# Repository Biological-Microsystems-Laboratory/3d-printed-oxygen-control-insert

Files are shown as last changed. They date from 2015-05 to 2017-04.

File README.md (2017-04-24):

# 3d-printed-oxygen-control-insert
### A 3D-printable microfluidic device for controlling dissolved gas environment in a 24-well culture plate

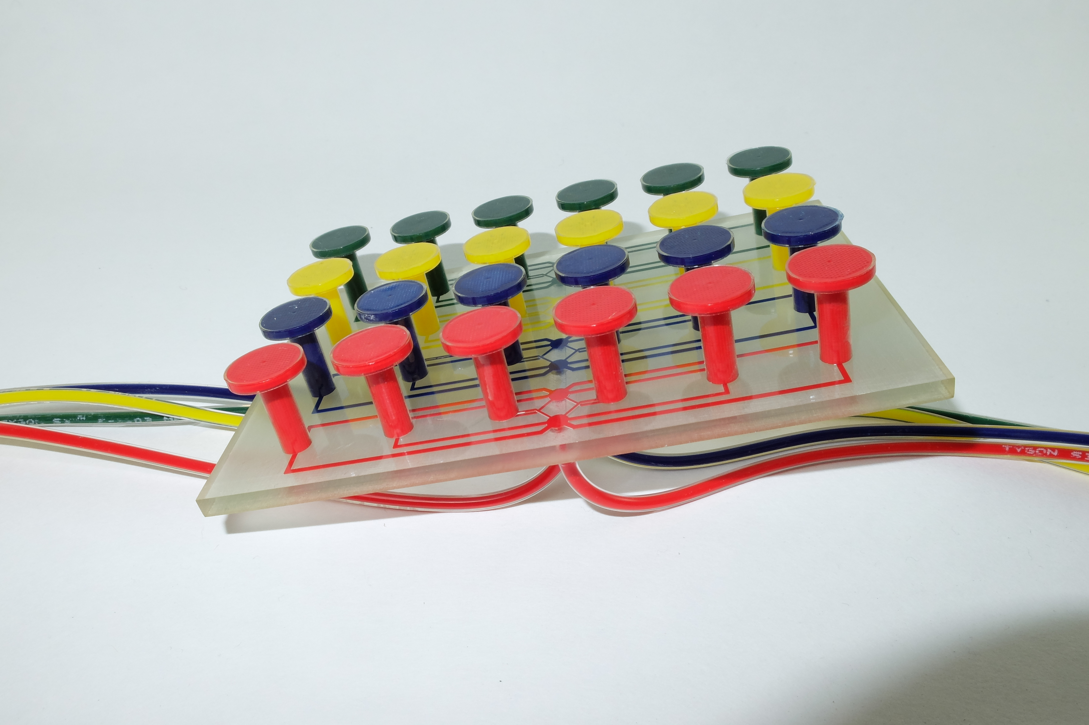
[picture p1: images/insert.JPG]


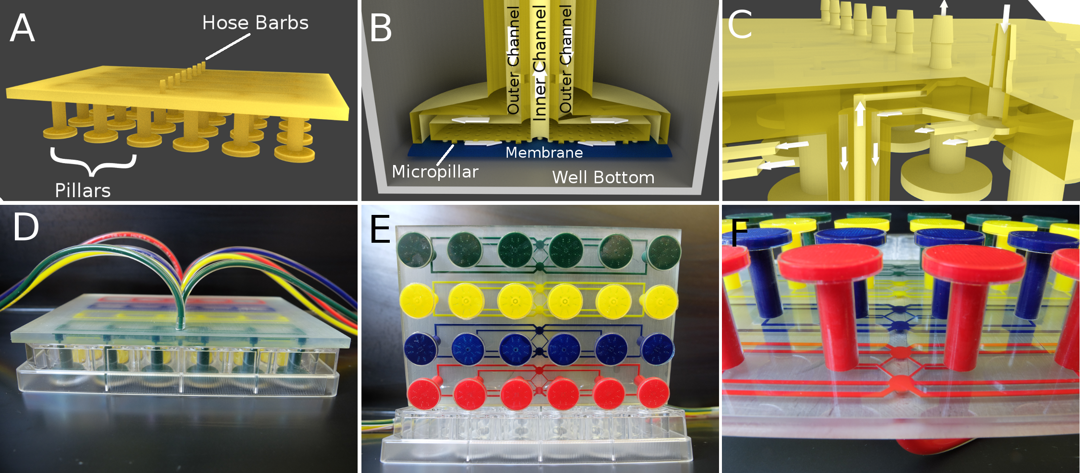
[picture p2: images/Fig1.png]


#### The device is printed complete with embedded channels and hose barbs. A 150 micrometer PDMS membrane is adhered to the pillar bottoms to complete the fluidic network and facilitate gas diffusion. Dissolved gas can be controlled in four 6-well units of a 24-well plate. 

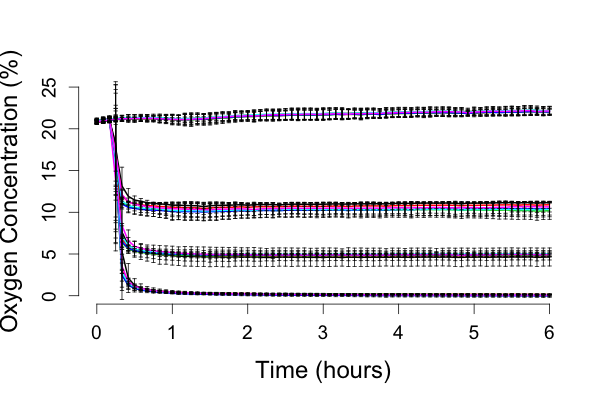
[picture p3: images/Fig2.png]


#### Dissolved oxygen at the cell culture surface can be modulated to near zero or up to 4 discrete levels.

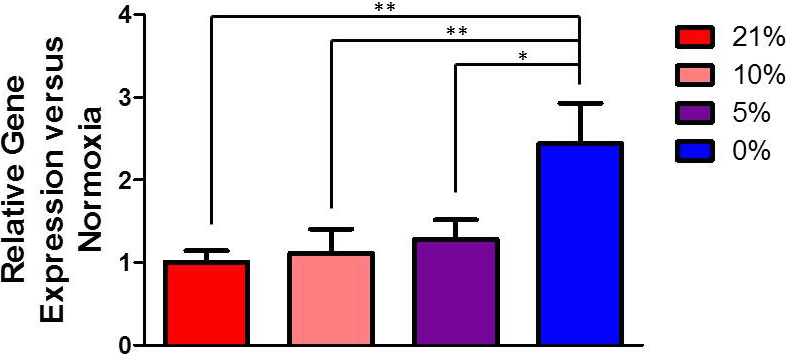
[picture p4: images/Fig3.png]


#### Oxygen levels influence VEGFA expression in A594 cells.

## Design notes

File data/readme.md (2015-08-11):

Data Plan
---
Demonstrate each row of 6 wells applying the condition of 0 5 10 or 21.

Calibrate with conditions of 0%, 1%, 7.5%, 15%, and 21%.

Calibration Procedure
------

1. Bring all wells to 0% with sodium sulfite (2 g/L) and device running with 0%. ~2hrs take final points as zero
2. With fresh water take wells to zero with 0% tank. ~2hrs
3. Switch to 1% tank. Take 1% calibration point. ~ 20 min
4. Switch to 7.5% tank. Take cal point. ~ 20 min
5. Switch to 15% tank. Take cal point. ~ 20 min
6. Exchange plate with fresh room equilibrated water. Switch to 21% tank Take cal point.

Charaterization Procedure
----
1. Change set-up to experimental tanks (0%, 5%, 10% and 21%)
2. Start all rows pulling room air.
3. Take acquisition every 5 min for 6 hrs.
4. Start pulling the characterization condition for each well after third timepoint.

Data organization
---

Intensities for each trial (N) will be stored here rather then raw images.

Intensities calibration matrix 24:5 (C:R) and characterization matrix 24:73

Detail Set-up
------------
4 CGA 500 two-stage regulators
2 Omega foating ball adjustable flow meters (FL-5311G rotameters)
#### Air Tanks
0%   O2, 5% CO2, bal. N2 tank
1%   O2, 5% CO2, bal. N2 tank; BI NICDOXC5-K
5%   O2, 5% CO2, bal. N2 tank; BI NICDOXC1-K
7.5% O2, 5% CO2, bal. N2 tank; BI NICD5017-K
10%  O2, 5% CO2, bal. N2 tank; BI NICDOX C21-K
15%  O2, 5% CO2, bal. N2 tank; BG NICDOXC43-K
21%  O2, 5% CO2, bal. N2 tank; BI NICDOXC4-K
Air tank, atomospheric mix

Sodium Sulfite (SS)

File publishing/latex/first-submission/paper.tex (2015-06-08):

% Template for PLoS
% Version 3.1 February 2015
%
% To compile to pdf, run:
% latex plos.template
% bibtex plos.template
% latex plos.template
% latex plos.template
% dvipdf plos.template
%
% % % % % % % % % % % % % % % % % % % % % %
%
% -- IMPORTANT NOTE
%
% This template contains comments intended 
% to minimize problems and delays during our production 
% process. Please follow the template instructions
% whenever possible.
%
% % % % % % % % % % % % % % % % % % % % % % % 
%
% Once your paper is accepted for publication, 
% PLEASE REMOVE ALL TRACKED CHANGES in this file and leave only
% the final text of your manuscript.
%
% There are no restrictions on package use within the LaTeX files except that 
% no packages listed in the template may be deleted.
%
% Please do not include colors or graphics in the text.
%
% Please do not create a heading level below \subsection. For 3rd level headings, use \paragraph{}.
%
% % % % % % % % % % % % % % % % % % % % % % %
%
% -- FIGURES AND TABLES
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
% - Figures generated using LaTeX should be extracted and removed from the PDF before submission. 
% - Figures containing multiple panels/subfigures must be combined into one image file before submission.
% For figure citations, please use "Fig." instead of "Figure".
% See http://www.plosone.org/static/figureGuidelines for PLOS figure guidelines.
%
% Tables should be cell-based and may not contain:
% - tabs/spacing/line breaks within cells to alter layout or alignment
% - vertically-merged cells (no tabular environments within tabular environments, do not use \multirow)
% - colors, shading, or graphic objects
% See http://www.plosone.org/static/figureGuidelines#tables for table guidelines.
%
% For tables that exceed the width of the text column, use the adjustwidth environment as illustrated in the example table in text below.
%
% % % % % % % % % % % % % % % % % % % % % % % %
%
% -- EQUATIONS, MATH SYMBOLS, SUBSCRIPTS, AND SUPERSCRIPTS
%
% IMPORTANT
% Below are a few tips to help format your equations and other special characters according to our specifications. For more tips to help reduce the possibility of formatting errors during conversion, please see our LaTeX guidelines at http://www.plosone.org/static/latexGuidelines
%
% Please be sure to include all portions of an equation in the math environment.
%
% Do not include text that is not math in the math environment. For example, CO2 will be CO\textsubscript{2}.
%
% Please add line breaks to long display equations when possible in order to fit size of the column. 
%
% For inline equations, please do not include punctuation (commas, etc) within the math environment unless this is part of the equation.
%
% % % % % % % % % % % % % % % % % % % % % % % % 
%
% Please contact latex@plos.org with any questions.
%
% % % % % % % % % % % % % % % % % % % % % % % %

\documentclass[10pt,letterpaper]{article}
\usepackage[top=0.85in,left=2.75in,footskip=0.75in]{geometry}

% Use adjustwidth environment to exceed column width (see example table in text)
\usepackage{changepage}

% Use Unicode characters when possible
\usepackage[utf8]{inputenc}

% textcomp package and marvosym package for additional characters
\usepackage{textcomp,marvosym}

% fixltx2e package for \textsubscript
\usepackage{fixltx2e}

% amsmath and amssymb packages, useful for mathematical formulas and symbols
\usepackage{amsmath,amssymb}
\usepackage[version=3]{mhchem}  % added by author

% cite package, to clean up citations in the main text. Do not remove.
\usepackage{cite}

% Use nameref to cite supporting information files (see Supporting Information section for more info)
\usepackage{nameref,hyperref}

% line numbers
\usepackage[right]{lineno}

% ligatures disabled
\usepackage{microtype}
\DisableLigatures[f]{encoding = *, family = * }

% rotating package for sideways tables
\usepackage{rotating}

% Remove comment for double spacing
%\usepackage{setspace} 
%\doublespacing

% Text layout
\raggedright
\setlength{\parindent}{0.5cm}
\textwidth 5.25in 
\textheight 8.75in

% Bold the 'Figure #' in the caption and separate it from the title/caption with a period
% Captions will be left justified
\usepackage[aboveskip=1pt,labelfont=bf,labelsep=period,justification=raggedright,singlelinecheck=off]{caption}

% Use the PLoS provided BiBTeX style
\bibliographystyle{plos2015}

% Remove brackets from numbering in List of References
\makeatletter
\renewcommand{\@biblabel}[1]{\quad#1.}
\makeatother

% Leave date blank
\date{}

% Header and Footer with logo
\usepackage{lastpage,fancyhdr,graphicx}
\usepackage{epstopdf}
\pagestyle{myheadings}
\pagestyle{fancy}
\fancyhf{}
\lhead{}
\rfoot{\thepage/\pageref{LastPage}}
\renewcommand{\footrule}{\hrule height 2pt \vspace{2mm}}
\fancyheadoffset[L]{2.25in}
\fancyfootoffset[L]{2.25in}
\lfoot{\sf PLOS}

%% Include all macros below

\newcommand{\lorem}{{\bf LOREM}}
\newcommand{\ipsum}{{\bf IPSUM}}

%% END MACROS SECTION

\begin{document}
\vspace*{0.35in}

% Title must be 250 characters or less.
% Please capitalize all terms in the title except conjunctions, prepositions, and articles.
\begin{flushleft}
{\Large
\textbf\newline{3D-Printed 24-Well Plate Oxygen Control Device - Submission to PLOS ONE}
}
\newline
% Insert author names, affiliations and corresponding author email (do not include titles, positions, or degrees).
\\
Martin D. Brennan\textsuperscript{1},
Megan L. Rexius-Hall\textsuperscript{1},
David T. Eddington\textsuperscript{1,*},
\\
\bigskip
\bf{1} Dept of Bioengineering, University of Illinois at Chicago, Chicago, Illinois, USA
\\
\bigskip

% Use the asterisk to denote corresponding authorship and provide email address in note below.
* dte@uic.edu

\end{flushleft}
% Please keep the abstract below 300 words
\section*{Abstract}
Recently 3D printing has emerged as a method for directly printing complete microfluidic devices, although printing materials have been limited to oxygen-impermeable materials.
We demonstrate the addition of gas permeable PDMS (Polydimethylsiloxane) membranes to 3D-printed microfluidic devices as a means to enable oxygen control cell culture studies.
The incorporation of a 3D-printed device and gas-permeable membranes was demonstrated on a 24-well oxygen control device for standard multiwell plates.
The direct printing allows integrated distribution channels and device geometries not possible with traditional planar lithography.
With this device, four different oxygen conditions were able to be controlled, and six wells were maintained under each oxygen condition. 
We demonstrate enhanced transcription of the gene VEGFA (vascular endothelial growth factor A) with decreasing oxygen levels in human lung adenocarcinoma cells.
This is the first 3D-printed device that can be functionalized to control oxygen in cell culture.

\linenumbers

\section*{Introduction}
Here we report on the development of 3D-printed microfluidic devices for the control of oxygen in cell culture microenvironments.
We demonstrate a device that nests into a 24-well culture plate to control gas in each row of the plate independently of the incubator's condition.
This expands on our previous work of a device fabricated using PDMS molds and planar lithography for 6-well plates\cite{Oppegard2009,Oppegard2010}.
The ability to independently control oxygen across each row of the plate enables more efficient experiments as a separate incubator or hypoxic chamber is not needed for each condition.

3D printing of microfluidic devices enables rapid, one-step fabrication of complex designs infeasible to make with planar lithography and replica molding techniques\cite{Waldbaur2011,Chen2014a}.
In addition, planar lithography is time consuming, requires specialized equipment and facilities, and has a high failure rate.
It is not unusual for microfluidic labs to make ten microfluidic devices to guarantee one will work properly.
On the other hand, 3D CAD printing allows for unambiguous specifications and nearly eliminates time and effort spent on fabrication which may be outsourced to a 3D printing company for around \$200/device \cite{Au2014}.
3D printing also allows integration of complex geometries not possible with planar lithography, such as hose barbs and luer fittings.
Dissemination and distributed production is also vastly simplified due to easy sharing of the design as a CAD file.
Due to these inherent advantages 3D printing has emerged as a method for directly printing complete microfluidic devices \cite{Au2014,Comina2014, Chen2014,Shallan2014,Bhargava2014}. 
Many prototypical microfluidic device features have been recreated with 3D printing as a proof of concept for this new fabrication technique \cite{ Au2014, Shallan2014} including modular re-configurable units\cite{Yuen2008,Bhargava2014,Lee2014}.
3D printed devices have been used for neuroengineering applications\cite{Tek2008}, inexpensive and high-throughput reactionware,\cite{Kitson2012,Symes2012,Kitson2013,Kitson2014}, culturing and imaging arrays of seedlings\cite{Busch2012}, measuring dopamine and ATP levels in biological samples with an integrated electrode\cite{Erkal2014}, or plate reader\cite{Chen2014}, and a bacteria separation flow assay\cite{Lee2014a,Lee2015}. 
Other 3D-printed fluidic devices include pneumatic valves\cite{Au2015} a custom NMR cell\cite{Causier2015}, a rapid reconstitution package for lyophilized drugs\cite{Chi2014} and flow plates for a water electrolysis system\cite{Chisholm2014}.

Printing is currently limited in choice of substrate compatible with the 3D printing process.
Substrate options include many proprietary formulations which have been successfully used in a variety of applications.
New techniques for using 3D-printed molds to produce devices\cite{Mcdonald2002,Gregory2013,King2014,Comina2014a,Kamei2015} are also being developed, including fugitive ink methods\cite{Therriault2003,Miller2012,Bhargava2015}.
To date, there are no widely available methods or materials to facilitate direct printing of gas-permeable materials, although this area is actively being explored\cite{Femmer2014a}.
Microfluidic cell culture devices are most commonly cast in PDMS as it is a convenient material for cell studies due to its biocompatibility, optical properties, and gas permeability, facilitating oxygen control of cell environments\cite{Sia2003,Brennan2014}.

Oxygen control in cells studies is often overlooked by researchers, but important for mimicking conditions experienced by cells in vivo.
Typically cell culture studies are performed at 21\% oxygen, atmospheric oxygen conditions, although levels that cells experience in vivo are less than 21\% \cite{Brennan2014}.
For example, tumors are generally hypoxic as cancer cells rapidly outgrow their vasculature creating a poorly perfused, hypoxic inner region\cite{Kumar2014}.
Studying cancer cells under controlled hypoxic conditions is important in understanding the pathophysiology because research has shown hypoxia may enhance aggressive phenotypes, tumor progression, metastasis, and resistance to therapy\cite{Vaupel2004,Vaupel2007,Gilkes2014}.
Hypoxia is known to alter the transcription of many genes which are under the activity of the HIF (hypoxia inducible factor) family of transcriptional factors\cite{Ke2006,Semenza1999,Semenza2002}.
To better study the role of oxygen levels in cancer gene expression, a gas controlled culture system is required.

Previously, we developed multiwell inserts for 6-well plates that controlled oxygen in a standard off-the shelf well plate \cite{Oppegard2009, Oppegard2010}.
These devices were completely cast from PDMS and fabricated in a multiple bonding procedure.
In addition, tubing was used to connect each pillar which became quite cumbersome when moving to a newer 24-well version.
Utilizing 3D printing for the fabrication allowed further features to be incorporated such as integrated distribution channels to eliminate the connection tubings between wells and hose barbs for better tubing connections, while eliminating fabrication time and failure rate.
Although available 3D printable materials are gas-impermeable, the addition of a PDMS membrane following printing of the passive microfluidic network is a simple addition allowing gas transfer. 
In this case, having a gas-impermeable material for the bulk is advantageous as it reduces unwanted gas transfer from the bulk material prior to the gas exchange interface.
The previous PDMS devices were Parylene coated along the convection channels to eliminate exchange of gas from the PDMS bulk, which again added to their complexity and is no longer needed.
Convection and distribution of the gas is done in the impermeable material, eliminating dilution of the gas before reaching the diffusion layer. 

% You may title this section "Methods" or "Models". 
% "Models" is not a valid title for PLoS ONE authors. However, PLoS ONE
% authors may use "Analysis" 
\section*{Materials and Methods}
\subsection*{Design of insert}

The device was designed to integrate with a multiwell format, specifically an off-the-shelf 24-well plate. 
The 24-well plate insert was designed to control gas in 4 rows of 6 wells each. 
Each of the 4 rows can be controlled independently from an input and also incorporates an integrated distribution network and hose barbs to simplify device operation.
The pillars extend into each well leaving a $\sim$500 $\mu$m gap for media between the diffusion membrane and the culture surface at the bottom of the well.
Diffusion occurs rapidly across this gap allowing control of the dissolved gas environment around the cells. 
A distribution network stems from the central input that equalizes the flow along each path length by varying the channel width to the proximal, intermediate, and distal wells (Fig.~\ref{fig1}).
The device also features a pipe within a pipe design so that gas flow enters and leaves the diffusion area in a uniform, and symmetrical flow pattern, which would not be possible with standard lithography and demonstrates the capabilities of 3D printing (Fig.~\ref{fig1}).

\begin{figure}[h]
\caption{
{\bf Design of 24-well Insert Device.}
(A) Rendering of whole 3D printed part.
An inlet and outlet barb allows perfusion of gas to control 6 wells.
(B) At the bottom of each pillar gas entering from the outer channel flows along the PDMS membrane (blue), which is supported by micropillars, and exhausts via the inner pipe.
Diffusion occurs rapidly through the PDMS membrane to the cell culture spaced 500 $\mu$m away at the bottom of the well.
(C) Cross-section demonstrating how the microfluidic distribution network and double pipes are connected. 
The two adjacent mirrored distribution networks are spaced 1 mm apart along the z-axis allowing them to overlap and enter the separate vertical pipes.
The arrows indicate the flow direction.
The incoming gas enters the outer pipe on its way to the bottom of the well and returns through the inner pipe.
(D) Photo of the device with dyed channels in a 24-well plate.
(E) Photo of the device from the bottom with four independent channel networks.
(F) Photo of the printed distribution networks.
}
\label{fig1}
\end{figure}

\subsection*{Fabrication of the insert}

CAD models were designed in Autodesk and Blender and printed via stereolithography in Watershed XC by Fineline Prototyping.
The 3D part contained the microfluidic delivery channels, and was completed by adhering a gas-permeable membrane of PDMS to enable diffusion of gas to the culture area. 
The PDMS membranes were fabricated by spin coating 10:1 PDMS (Sylgard 184) on a silicon wafer at 900 RPM to a thickness of $\sim$100 $\mu$m and curing at $70\,^{\circ}$C for 30 minutes.
The PDMS membrane was cut to size and attached to the 3D-printed network with an additional, thin layer of PDMS that was applied as an adhesive to the membrane, secured in position on the end of each pillar, and allowed to cure in place.

\subsection*{Oxygen characterization}

Oxygen was measured with PtOEPK (Pt(II) Octaethylporphine ketone) planar sensors that were fixed to the bottom of a 24-well plate.
Sensors were prepared as discussed previously \cite{Sinkala2010,Rexius-Hall2014}. 
Briefly, polystyrene was dissolved in toluene to form a solution to which PtOEPK (Frontier Scientific) was mixed in before spin coating to a thin layer and allowing the toluene to evaporate.
The intensity of the sensor was measured with via fluorescence microscopy and correlated to the concentration of oxygen with Stern-Volmer analysis.

Gas was pulled through the device with negative pressure as a precaution to avoid bulging or detaching membranes, as well as bubble formation in the culture media.
The outlet ports were connected to a water aspirator which pulled gas through the device from the inlet ports via a flow meter (FL-5311G; Omega) set at 50 ccm.
The inlet tubing was placed in an open cone that was flooded with gas from a tank with a flow rate of 30 ccm which exceed the vacuum flow rate (12.5 ccm per 6-well network) so that the gas of interest was pulled into the inlet rather than room air due to the open connection.
In this way, the pressure, and therefore flow rate, was equal across the 4 networks without having to balance flow from 4 pressurized sources, yet different gases of interest can be perfused via vacuum.

Initially the inlets are fed with a 5\% \ce{CO2}, balanced air tank until the intensity stabilized.
The inlets were then switched to the control gas of either 0, 5, 10, or 21\% \ce{O2}, each with 5\% \ce{CO2} and balanced with \ce{N2}.
Intensity measurements were then taken every five minutes for six hours.
All gas tanks used in the oxygen characterization were 5\% \ce{CO2}  in addition to the desired gas mix in anticipation of cell culture experiments (where \ce{CO2} is necessary to buffer the culture media) as \ce{CO2} can alter the fluorescence of the PtOEPK.
The this entire procedure was repeated three independent times. 

\subsection*{Cell culture}

Human lung adenocarcinoma (A549) cells were seeded at 30,000 cells per well in a 24-well plate.
Cells were cultured in DMEM supplemented with 10\% FBS.
After reaching $\sim$70\% confluency, the 24-well insert was placed in the plate and the gases were perfused through the device in the same scheme as in the oxygen characterization.
Each row of six wells experienced either 0\%, 5\%, 10\% or 21\% \ce{O2}, with 5\% \ce{CO2} and balanced nitrogen.
The assembly was placed in an incubator at $37\,^{\circ}$C for six hours. 

\subsection*{Quantitative PCR}

Following six hours of oxygen modulation, the 24-well oxygen control insert was removed and culture media was aspirated.
Cells in each well were washed twice with PBS, and 300 $\mu$L of a lysis solution consisting of 10 $\mu$L of $\beta$-mercaptoethanol (Sigma Aldrich) per 1 mL of lysis buffer (PureLink RNA Mini Kit; Invitrogen) was added to each well.
The lysate from each well was collected as a sample.
RNA was extracted according to the PureLink RNA Mini Kit manufacturer’s instructions.

Synthesis of cDNA was performed using the High-Capacity cDNA Reverse Transcription Kit (Applied Biosystems), and quantitative PCR was carried out on ABI PRISM 700O (Applied Biosystems) in 25 $\mu$L reactions using Taqman Gene Expression Assays.
Beta-2-microglobulin (B2M) served as the endogenous control for calculations of relative gene expression.
Six technical replicates from the 6-well control unit were processed for each of four oxygen conditions (0\%, 5\%, 10\% and 21\% \ce{O2}) in three independent experiments.

\subsection*{Statistical analysis}

Cell culture experiments were repeated three independent times. Data are expressed as the mean $\pm$ SD. One-way ANOVA with Tukey’s multiple comparison post-test performed by Prism 5 (Graphpad) determined significance.

% For figure citations, please use "Fig." instead of "Figure".
%Nulla mi mi, Fig.~\ref{fig1} venenatis sed ipsum varius, volutpat euismod diam. Proin rutrum vel massa non gravida. Quisque tempor sem et dignissim rutrum. Lorem ipsum dolor sit amet, consectetur adipiscing elit. Morbi at justo vitae nulla elementum commodo eu id massa. In vitae diam ac augue semper tincidunt eu ut eros. Fusce fringilla erat porttitor lectus cursus, \nameref{S1_Video} vel sagittis arcu lobortis. Aliquam in enim semper, aliquam massa id, cursus neque. Praesent faucibus semper libero.

%\begin{enumerate}
%\item{react}
%\item{diffuse free particles}
%\item{increment time by dt and go to 1}
%\end{enumerate}

% Results and Discussion can be combined.
\section*{Results}
\subsection*{Oxygen control}
Oxygen control in the 24-well insert device was quantified with a platinum-based (PtOEPK) planar oxygen sensor placed at the bottom of the well, as shown in Fig.~\ref{fig2}.
The device reaches steady state in 30 minutes and can then hold the oxygen level near 0\% \ce{O2} indefinitely, while 95\% \ce{N2}, 5\% \ce{CO2} is pumped through the device. 
A different gas condition can be used in each separate iteration of the 6-well unit allowing 6 technical replicates of up to 4 different gas conditions in one 24-well plate (Fig.~\ref{fig2}). There was little variation in the oxygen levels measured in each of the 6 wells controlled by a single inlet, demonstrating the distribution network worked effectively.

\begin{figure}[h]
\caption{
{\bf Oxygen Characterization.} 
(A) Time course data of oxygen being evacuated from the culture area as 0\% oxygen gas is perfused through the device.
Error bars are the standard deviation N=3.
(B) Four oxygen conditions are demonstrated in a 24-well plate.
Each 6-well row of the plate can be controlled independently.  
Mean N=3 error bars not included.
}
\label{fig2}
\end{figure}

\subsection*{Bioverifcation}

Oxygen levels of 21\%, 10\%, 5\%, and 0\% were applied to each set of 6 wells in which A549 cells were cultured.
Measurement of relative gene expression confirmed biological responsiveness of cells under the device’s control.
The device’s ability to control the gas environment was demonstrated with hypoxia-induced upregulation of VEGFA mRNA in the A549 cells (Fig.~\ref{fig3}).  Quantitative PCR showed a significant increase in the relative gene expression of VEGFA in wells exposed to 0\% \ce{O2} for 6 hours as compared to 21\% \ce{O2}. Hypoxia-induced alterations in gene expression usually indicate a HIF-transduced hypoxic signal in cells.
When a HIF transcription factor undergoes nuclear translocation, it can initiate transcription of genes by binding to the hypoxia response element (HRE)\cite{Lee2004} on its target genes.
VEGFA has previously been shown to have a functional HRE, and upregulation has been observed in A549 cells under hypoxic conditions\cite{RohrerBley2011}.

\begin{figure}[h]
\caption{
{\bf PCR Data.}  VEGFA expression in A549 cells after exposure to different oxygen conditions set-up by the insert device. Data are expressed as mean $\pm$ SD, N=3.
}
\label{fig3}
\end{figure}

\subsection*{Discussion}
This new iteration of the multi-well insert for oxygen control maintains the convenient features of the previous design while improving distribution and interfacing with tubing due to the 3D-printed element.
Oxygen control is performed in an off-the-shelf culture plate allowing standard protocols to be used for analysis assays or imaging where additional protocols are often required when cells are seeded within microfluidic chips.
The VEGFA gene expression in A549 cells confirms a biological response using the multi-well insert.

This 3D-printed device improves on our previous design in a number of ways.
First, the fabrication is greatly simplified. 
No microfabrication, PDMS molding or Parylene coating is required.
Additionally, the non-permanent adhesion of membranes to the 3D-part allow them to be removed and replaced if they are damaged.
In PDMS devices the layers are bonded permanently via plasma bonding so damage to a membrane is not repairable.
3D-printing also enables higher levels of intricacy without any additional fabrication, allowing us to include the distribution network, overlapping of channels in the z-axis, and the 'pipe within a pipe' design. 
A comparable PDMS device would require several additional microfabricated layers to be manually aligned to reproduce just the distribution network.

Moving forward with additive manufacturing of microfluidic devices is desirable as it will enable highly integrated designs without any additional fabrication.
For this device an in-device gas mixer could allow more conditions in a single plate, perhaps even one per well or even gradients within wells while reducing the number of gas tanks required as inputs.
This design could also be applied to higher format plates such as 96-well plates.

\section*{Conclusion}
3D printing microfluidic chips have been limited to oxygen-impermeable materials.
We demonstrate oxygen control in 3D-printed devices with the addition of a gas permeable PDMS membrane. 
Oxygen control is demonstrated in a 24-well plate and PCR detection of upregulation of VEGFA mRNA in A549 cells shows the device effectively controls oxygen as expected. 
3D printing allows complex designs, integrated tubing connectors, and is comparable in price to standard PDMS fabrication. 
This technique represents a bridge to commercialization where robust devices can be more easily shared and disseminated. 
While injection molding, hot embossing, or other industrial processes are cheaper when making hundreds to thousands of devices, it is not practical to make an injection mold when making tens to hundreds of devices. 
In addition, PDMS fabrication would be too time consuming, expensive, and the failure rate would be unacceptable. 3D printing is an excellent solution to these device fabrication needs.

%\begin{table}[!ht]
%\begin{adjustwidth}{-2.25in}{0in} % Comment out/remove adjustwidth environment if table fits in text column.
%\caption{
%{\bf Table caption Nulla mi mi, venenatis sed ipsum varius, volutpat euismod diam.}}
%\begin{tabular}{|l|l|l|l|l|l|l|l|}
%\hline
%\multicolumn{4}{|l|}{\bf Heading1} & \multicolumn{4}{|l|}{\bf Heading2}\\ \hline
%$cell1 row1$ & cell2 row 1 & cell3 row 1 & cell4 row 1 & cell5 row 1 & cell6 row 1 & cell7 row 1 & cell8 row 1\\ %\hline
%$cell1 row2$ & cell2 row 2 & cell3 row 2 & cell4 row 2 & cell5 row 2 & cell6 row 2 & cell7 row 2 & cell8 row 2\\ %\hline
%$cell1 row3$ & cell2 row 3 & cell3 row 3 & cell4 row 3 & cell5 row 3 & cell6 row 3 & cell7 row 3 & cell8 row 3\\ %\hline
%\end{tabular}
%\begin{flushleft} Table notes Phasellus venenatis, tortor nec vestibulum mattis, massa tortor interdum felis, nec %pellentesque metus tortor nec nisl. Ut ornare mauris tellus, vel dapibus arcu suscipit sed.
%\end{flushleft}
%\label{table1}
%\end{adjustwidth}
%\end{table}

% Please do not create a heading level below \subsection. For 3rd level headings, use \paragraph{}. 
%For more information, see \nameref{S1_Text}.

%\section*{Supporting Information}

% Include only the SI item label in the subsection heading. Use the \nameref{label} command to cite SI items in the text.
%\subsection*{S1 Video}
%\label{S1_Video}
%{\bf Bold the first sentence.}  Maecenas convallis mauris sit amet sem ultrices gravida. Etiam eget sapien nibh. %Sed ac ipsum eget enim egestas ullamcorper nec euismod ligula. Curabitur fringilla pulvinar lectus consectetur %pellentesque.

%\subsection*{S1 Text}
%\label{S1_Text}
%{\bf Lorem Ipsum.} Maecenas convallis mauris sit amet sem ultrices gravida. Etiam eget sapien nibh. Sed ac %ipsum eget enim egestas ullamcorper nec euismod ligula. Curabitur fringilla pulvinar lectus consectetur %pellentesque.

%\subsection*{S1 Fig}
%\label{S1_Fig}
%{\bf Lorem Ipsum.} Maecenas convallis mauris sit amet sem ultrices gravida. Etiam eget sapien nibh. Sed ac %ipsum eget enim egestas ullamcorper nec euismod ligula. Curabitur fringilla pulvinar lectus consectetur %pellentesque.

%\subsection*{S2 Fig}
%\label{S2_Fig}
%{\bf Lorem Ipsum.} Maecenas convallis mauris sit amet sem ultrices gravida. Etiam eget sapien nibh. Sed ac %ipsum eget enim egestas ullamcorper nec euismod ligula. Curabitur fringilla pulvinar lectus consectetur %pellentesque.

%\subsection*{S1 Table}
%\label{S1_Table}
%{\bf Lorem Ipsum.} Maecenas convallis mauris sit amet sem ultrices gravida. Etiam eget sapien nibh. Sed ac %ipsum eget enim egestas ullamcorper nec euismod ligula. Curabitur fringilla pulvinar lectus consectetur %pellentesque.

\section*{Acknowledgments}
%This work funded by NSF 1253060.

\nolinenumbers

%\section*{References}
\bibliographystyle{plos2015.bst}
\bibliography{references}

\end{document}

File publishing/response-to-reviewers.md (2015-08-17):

PONE-D-15-17915

A 3D-Printed Oxygen Control Insert for a 24-Well Plate

PLOS ONE

Dear Arum Han and reviewers,

Thank you for reviewing our manuscript submission to PLOS ONE. We have made several improvements and clarifications resulting what we hope is a stronger manuscript ready for publication.

In addition to this rebuttal letter a clean revised manuscript is submitted as well as a marked-up copy with tracked changes. 

Yours sincerely, 

David Eddington, Ph.D.
University of Illinois at Chicago

**Authors' Rebuttal to Reviewers:**

**Reviewer #1:**

It is a different version of design to control oxygen in cell culture, among some recent efforts. One concern is that the group has published quite a number of papers on oxygen control devices, although it is now through 3d printing. It is important to highlight in front the key improvements.

* **Authors' rebuttal:** 
An overview of improvements from our previous PDMS cast devices starts on line 51 of the original manuscript, now line 64 of the revised manuscript.

Also, it is important to compare with some other methods related to 3d printing such as that done recently by Kamei K. et al. (Biomed Microdevices. 2015 Apr;17(2):36). 

* **Authors' rebuttal:** 
The work by Kamei et al. was cited along with several other papers that used 3D printed parts as molds for PDMS devices on line 33 of the original manuscript, now line 46 of the revised manuscript.

"This is the first 3D-printed device that can be functionalized to control oxygen in cell culture" is a statement which is too strong.

* **Authors' rebuttal:** 
The wording was changed to "This is first 3D-printed device incorporating gas permeable membranes to facilitate oxygen control in cell culture."

**Reviewer #2:**

Currently, little consideration is given to mimicking physiological oxygen concentrations in vitro during cell experiments. Oftentimes cells are cultured at atmospheric oxygen conditions which are higher than what is found in many tissues, including tumor environments. Some systems have been developed to control the oxygen environment in vitro, but these can be cumbersome or costly to implement. 3D printing has emerged as a rapid prototyping method to fabricate devices with high control over structure and therefore is an attractive method to design a microfluidic device capable of controlling oxygen concentrations in culture. Brennan et al. report on a 3D printed control device capable of adjusting oxygen concentrations in a 24-well plate. Although the concept is interesting, the data is not sufficient and additional experiments are needed to improve the manuscript. 

Page 3 - In addition to presenting gap distance below insert and well bottom, it would be helpful if the authors included volume of media this space would hold. 

* **Authors' rebuttal:**
A sentence was added including the approximate volume of media in the gap. See line 87 of the revised manuscript.

Page 4 – Why was 6 hrs chosen for cell culture? It would seem that the authors could demonstrate a more robust change in expression over the concentrations tested if the experiment was extended to a longer time point, especially considering only the 0% group showed a significant difference in VEGFA expression.

* **Authors' rebuttal:** 
VEGFA is under the transcriptional activity of HIF-1alpha. The time course of HIF-1alpha protein levels in A549 cells demonstrates maximal protein levels at 4 h and a steep decrease in expression by 16 h. Based on the known time course, we looked at a time point slightly delayed from the 4 h peak to account for transcription of the downstream target gene of interest (VEGFA). At longer time points, HIF protein expression is actually suppressed, and many transcripts are not increased with extended duration. This additional information was added along with a citation starting at line 182.

The authors specify concentrations of 21%, 10%, 5%, and 0% were evaluated, however in their Figure 2b, the concentrations appear closer to 13% (not 10%) and 7% (not 5%). Variation of 3% can be considerable in physiological environments and it is unclear if the authors recognize this variation. It is also amplified by the lack of error bars for each group.

* **Authors' rebuttal:**
The data in the original submission was analyzed with a two point calibration. This method correlates intensities to oxygen concentration assuming a linear Stern-Volmer relationship. While standard practice, the two-point calibration suffers from increasing inaccuracy as points are measured further away from the calibration points. Characterization data was re-taken with 5 calibration points and analyzed with a two-site Stern-Volmer model to increase accuracy of analyzed data. A new plot replaces figure 2 and includes error bars.

Is sterilization an issue for this device, considering it will be in close contact with biological components? 

* **Authors' rebuttal:**
Sterilization was preformed by spraying the device with 70% ethanol and leaving it in a biosaftey hood with UV lights overnight. We did not observe any contamination. This information was added to the manuscript. See lines 131, and 141.

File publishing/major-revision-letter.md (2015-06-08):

PONE-D-15-17915
3D-Printed 24-Well Plate Oxygen Control Device
PLOS ONE

Dear Prof. Eddington,

Thank you for submitting your manuscript to PLOS ONE. After careful consideration, we feel that it has merit, but is not suitable for publication as it currently stands. Therefore, my decision is "Major Revision." 

We invite you to submit a revised version of the manuscript that addresses the points below, especially those by Reviewer #2.

We encourage you to submit your revision within forty-five days of the date of this decision. 

When your files are ready, please submit your revision by logging on to http://pone.edmgr.com/ and following the Submissions Needing Revision link. Do not submit a revised manuscript as a new submission. Before uploading, you should proofread your manuscript very closely for mistakes and grammatical errors. Should your manuscript be accepted for publication, you may not have another chance to make corrections as we do not offer pre-publication proofs.

If you would like to make changes to your financial disclosure, please include your updated statement in your cover letter. 

In addition, when submitting your revision please include the following items: 

A rebuttal letter that responds to each point brought up by the academic editor and reviewer(s). This letter should be uploaded as a 'Response to Reviewers' file.

A clean revised manuscript as your 'Manuscript' file.

A marked-up copy of the changes made from the previous article file as a 'Revised Manuscript with Track Changes' file. This can be done using 'track changes' in programs such as MS Word and/or highlighting any changes in the new document.

For more information on how to upload your revised submission, see our video: http://blogs.plos.org/everyone/2011/05/10/how-to-submit-your-revised-manuscript/

If you choose not to submit a revision, please notify us. 

Yours sincerely, 

Arum Han, Ph.D.
Academic Editor
PLOS ONE

Journal requirements:

1. When submitting your revision, we need you to address these additional requirements.

Please ensure that your manuscript meets PLOS ONE’s style requirements, including those for file naming. The PLOS ONE style templates can be found at http://www.plosone.org/attachments/PLOSOne_formatting_sample_main_body.pdf and http://www.plosone.org/attachments/PLOSOne_formatting_sample_title_authors_affiliations.pdf

[Note: HTML markup is below. Please do not edit.]

Reviewers' comments:

Reviewer's Responses to Questions

Comments to the Author

1. Is the manuscript technically sound, and do the data support the conclusions?

The manuscript must describe a technically sound piece of scientific research with data that supports the conclusions. Experiments must have been conducted rigorously, with appropriate controls, replication, and sample sizes. The conclusions must be drawn appropriately based on the data presented. 

Reviewer #1: Yes

Reviewer #2: Yes

2. Has the statistical analysis been performed appropriately and rigorously? 

Reviewer #1: Yes

Reviewer #2: Yes

3. Does the manuscript adhere to the PLOS Data Policy?

Authors must follow the PLOS Data policy, which requires authors to make all data underlying the findings described in their manuscript fully available without restriction. Please refer to the author’s Data Availability Statement in the manuscript. All data and related metadata must be deposited in an appropriate public repository, unless already provided as part of the submitted article or supporting information. If there are restrictions on the ability of authors to publicly share data—e.g. privacy or use of data from a third party— these reasons must be specified.

Reviewer #1: Yes

Reviewer #2: Yes

4. Is the manuscript presented in an intelligible fashion and written in standard English?

PLOS ONE does not copyedit accepted manuscripts, so the language in submitted articles must be clear, correct, and unambiguous. Any typographical or grammatical errors should be corrected at revision, so please note any specific errors here.

Reviewer #1: Yes

Reviewer #2: Yes

5. Review Comments to the Author

Please use the space provided to explain your answers to the questions above. You may also include additional comments for the author, including concerns about dual publication, research ethics, or publication ethics. (Please upload your review as an attachment if it exceeds 20,000 characters)

Reviewer #1: It is a different version of design to control oxygen in cell culture, among some recent efforts. One concern is that the group has published quite a number of papers on oxygen control devices, although it is now through 3d printing. It is important to highlight in front the key improvements. 

Also, it is important to compare with some other methods related to 3d printing such as that done recently by Kamei K. et al. (Biomed Microdevices. 2015 Apr;17(2):36). 

"This is the first 3D-printed device that can be functionalized to control oxygen in cell culture" is a statement which is too strong.

Reviewer #2: Currently, little consideration is given to mimicking physiological oxygen concentrations in vitro during cell experiments. Oftentimes cells are cultured at atmospheric oxygen conditions which are higher than what is found in many tissues, including tumor environments. Some systems have been developed to control the oxygen environment in vitro, but these can be cumbersome or costly to implement. 3D printing has emerged as a rapid prototyping method to fabricate devices with high control over structure and therefore is an attractive method to design a microfluidic device capable of controlling oxygen concentrations in culture. Brennan et al. report on a 3D printed control device capable of adjusting oxygen concentrations in a 24-well plate. Although the concept is interesting, the data is not sufficient and additional experiments are needed to improve the manuscript. 
•	Page 3 - In addition to presenting gap distance below insert and well bottom, it would be helpful if the authors included volume of media this space would hold. 
•	Page 4 – Why was 6 hrs chosen for cell culture? It would seem that the authors could demonstrate a more robust change in expression over the concentrations tested if the experiment was extended to a longer time point, especially considering only the 0% group showed a significant difference in VEGFA expression. 
•	The authors specify concentrations of 21%, 10%, 5%, and 0% were evaluated, however in their Figure 2b, the concentrations appear closer to 13% (not 10%) and 7% (not 5%). Variation of 3% can be considerable in physiological environments and it is unclear if the authors recognize this variation. It is also amplified by the lack of error bars for each group.
•	Is sterilization an issue for this device, considering it will be in close contact with biological components? 

Overall, the investigators demonstrate a unique method to controlling cell culture conditions; however additional steps should be taken to demonstrate precision of this method, particularly for a short, proof-of-concept manuscript.

6. If you would like your identity to be revealed to the authors, please include your name here (optional).

Your name and review will not be published with the manuscript. 

Reviewer #1: (No Response)

Reviewer #2: (No Response)

[NOTE: If reviewer comments were submitted as an attachment file, they will be attached to this email and accessible via the submission site. Please log into your account, locate the manuscript record, and check for the action link "View Attachments". If this link does not appear, there are no attachment files to be viewed.]

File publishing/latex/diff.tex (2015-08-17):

% Template for PLoS
%DIF LATEXDIFF DIFFERENCE FILE
%DIF DEL first-submission/paper.tex   Thu Aug 13 14:04:36 2015
%DIF ADD revision/revision.tex        Fri Aug 14 15:17:56 2015
% Version 3.1 February 2015
%
% To compile to pdf, run:
% latex plos.template
% bibtex plos.template
% latex plos.template
% latex plos.template
% dvipdf plos.template
%
% % % % % % % % % % % % % % % % % % % % % %
%
% -- IMPORTANT NOTE
%
% This template contains comments intended 
% to minimize problems and delays during our production 
% process. Please follow the template instructions
% whenever possible.
%
% % % % % % % % % % % % % % % % % % % % % % % 
%
% Once your paper is accepted for publication, 
% PLEASE REMOVE ALL TRACKED CHANGES in this file and leave only
% the final text of your manuscript.
%
% There are no restrictions on package use within the LaTeX files except that 
% no packages listed in the template may be deleted.
%
% Please do not include colors or graphics in the text.
%
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
%
% Please be sure to include all portions of an equation in the math environment.
%
% Do not include text that is not math in the math environment. For example, CO2 will be CO\textsubscript{2}.
%
% Please add line breaks to long display equations when possible in order to fit size of the column. 
%
% For inline equations, please do not include punctuation (commas, etc) within the math environment unless this is part of the equation.
%
% % % % % % % % % % % % % % % % % % % % % % % % 
%
% Please contact latex@plos.org with any questions.
%
% % % % % % % % % % % % % % % % % % % % % % % %

\documentclass[10pt,letterpaper]{article}
\usepackage[top=0.85in,left=2.75in,footskip=0.75in]{geometry}

% Use adjustwidth environment to exceed column width (see example table in text)
\usepackage{changepage}

% Use Unicode characters when possible
\usepackage[utf8]{inputenc}

% textcomp package and marvosym package for additional characters
\usepackage{textcomp,marvosym}

% fixltx2e package for \textsubscript
\usepackage{fixltx2e}

% amsmath and amssymb packages, useful for mathematical formulas and symbols
\usepackage{amsmath,amssymb}
\usepackage[version=3]{mhchem}  % added by author

% cite package, to clean up citations in the main text. Do not remove.
\usepackage{cite}

% Use nameref to cite supporting information files (see Supporting Information section for more info)
\usepackage{nameref,hyperref}

% line numbers
\usepackage[right]{lineno}

% ligatures disabled
\usepackage{microtype}
\DisableLigatures[f]{encoding = *, family = * }

% rotating package for sideways tables
\usepackage{rotating}

% Remove comment for double spacing
%\usepackage{setspace} 
%\doublespacing

% Text layout
\raggedright
\setlength{\parindent}{0.5cm}
\textwidth 5.25in 
\textheight 8.75in

% Bold the 'Figure #' in the caption and separate it from the title/caption with a period
% Captions will be left justified
\usepackage[aboveskip=1pt,labelfont=bf,labelsep=period,justification=raggedright,singlelinecheck=off]{caption}

% Use the PLoS provided BiBTeX style
\bibliographystyle{plos2015}

% Remove brackets from numbering in List of References
\makeatletter
\renewcommand{\@biblabel}[1]{\quad#1.}
\makeatother

% Leave date blank
\date{}

% Header and Footer with logo
\usepackage{lastpage,fancyhdr,graphicx}
\usepackage{epstopdf}
\pagestyle{myheadings}
\pagestyle{fancy}
\fancyhf{}
\lhead{}
\rfoot{\thepage/\pageref{LastPage}}
\renewcommand{\footrule}{\hrule height 2pt \vspace{2mm}}
\fancyheadoffset[L]{2.25in}
\fancyfootoffset[L]{2.25in}
\lfoot{\sf PLOS}

%% Include all macros below

\newcommand{\lorem}{{\bf LOREM}}
\newcommand{\ipsum}{{\bf IPSUM}}

%% END MACROS SECTION

%DIF PREAMBLE EXTENSION ADDED BY LATEXDIFF
%DIF UNDERLINE PREAMBLE %DIF PREAMBLE
\RequirePackage[normalem]{ulem} %DIF PREAMBLE
\RequirePackage{color}\definecolor{RED}{rgb}{1,0,0}\definecolor{BLUE}{rgb}{0,0,1} %DIF PREAMBLE
\providecommand{\DIFadd}[1]{{\protect\color{blue}\uwave{#1}}} %DIF PREAMBLE
\providecommand{\DIFdel}[1]{{\protect\color{red}\sout{#1}}}                      %DIF PREAMBLE
%DIF SAFE PREAMBLE %DIF PREAMBLE
\providecommand{\DIFaddbegin}{} %DIF PREAMBLE
\providecommand{\DIFaddend}{} %DIF PREAMBLE
\providecommand{\DIFdelbegin}{} %DIF PREAMBLE
\providecommand{\DIFdelend}{} %DIF PREAMBLE
%DIF FLOATSAFE PREAMBLE %DIF PREAMBLE
\providecommand{\DIFaddFL}[1]{\DIFadd{#1}} %DIF PREAMBLE
\providecommand{\DIFdelFL}[1]{\DIFdel{#1}} %DIF PREAMBLE
\providecommand{\DIFaddbeginFL}{} %DIF PREAMBLE
\providecommand{\DIFaddendFL}{} %DIF PREAMBLE
\providecommand{\DIFdelbeginFL}{} %DIF PREAMBLE
\providecommand{\DIFdelendFL}{} %DIF PREAMBLE
%DIF END PREAMBLE EXTENSION ADDED BY LATEXDIFF

\begin{document}
\vspace*{0.35in}

% Title must be 250 characters or less.
% Please capitalize all terms in the title except conjunctions, prepositions, and articles.
\begin{flushleft}
{\Large
\textbf\DIFdelbegin %DIFDELCMD < \newline{3D-Printed 24-Well Plate Oxygen Control Device - Submission to PLOS ONE}
%DIFDELCMD < %%%
\DIFdelend \DIFaddbegin \newline{A 3D-Printed Oxygen Control Insert for a 24-Well Plate}
\DIFaddend }
\newline
% Insert author names, affiliations and corresponding author email (do not include titles, positions, or degrees).
\\
Martin D. Brennan\textsuperscript{1},
Megan L. Rexius-Hall\textsuperscript{1},
David T. Eddington\textsuperscript{1,*},
\\
\bigskip
\bf{1} Dept of Bioengineering, University of Illinois at Chicago, Chicago, Illinois, USA
\\
\bigskip

% Use the asterisk to denote corresponding authorship and provide email address in note below.
* dte@uic.edu

\end{flushleft}
% Please keep the abstract below 300 words
\section*{Abstract}
\DIFdelbegin \DIFdel{Recently }\DIFdelend 3D printing has emerged as a method for directly printing complete microfluidic devices, although printing materials have been limited to oxygen-impermeable materials.
We demonstrate the addition of gas permeable PDMS (Polydimethylsiloxane) membranes to 3D-printed microfluidic devices as a means to enable oxygen control cell culture studies.
The incorporation of a 3D-printed device and gas-permeable membranes was demonstrated on a 24-well oxygen control device for standard multiwell plates.
The direct printing allows integrated distribution channels and device geometries not possible with traditional planar lithography.
With this device, four different oxygen conditions were able to be controlled, and six wells were maintained under each oxygen condition. 
We demonstrate enhanced transcription of the gene VEGFA (vascular endothelial growth factor A) with decreasing oxygen levels in human lung adenocarcinoma cells.
This is the first 3D-printed device \DIFdelbegin \DIFdel{that can be functionalized to control oxygen }\DIFdelend \DIFaddbegin \DIFadd{incorporating gas permeable membranes to facilitate oxygen control }\DIFaddend in cell culture.
\DIFdelbegin %DIFDELCMD < 

%DIFDELCMD < %%%
\DIFdelend \linenumbers

\section*{Introduction}
Here we report on the development of 3D-printed microfluidic devices for the control of oxygen in cell culture microenvironments.
We demonstrate a device that nests into a 24-well culture plate to control gas in each row of the plate independently of the incubator's condition.
This expands on our previous work of a device fabricated using PDMS molds and planar lithography for 6-well plates\cite{Oppegard2009,Oppegard2010}.
The ability to independently control oxygen across each row of the plate enables more efficient experiments as a separate incubator or hypoxic chamber is not needed for each condition.

3D printing of microfluidic devices enables rapid, one-step fabrication of complex designs infeasible to make with planar lithography and replica molding techniques\cite{Waldbaur2011,Chen2014a}.
In addition, planar lithography is time consuming, requires specialized equipment and facilities, and has a high failure rate.
It is not unusual for microfluidic labs to make ten microfluidic devices to guarantee one will work properly.
On the other hand, 3D CAD printing allows for unambiguous specifications and nearly eliminates time and effort spent on fabrication which may be outsourced to a 3D printing company for around \$200/device \cite{Au2014}.
3D printing also allows integration of complex geometries not possible with planar lithography, such as hose barbs and luer fittings.
Dissemination and distributed production is also vastly simplified due to easy sharing of the design as a CAD file.
Due to these inherent advantages 3D printing has emerged as a method for directly printing complete microfluidic devices \cite{Au2014,Comina2014, Chen2014,Shallan2014,Bhargava2014}. 
Many prototypical microfluidic device features have been recreated with 3D printing as a proof of concept for this new fabrication technique \cite{ Au2014, Shallan2014} including modular re-configurable units\cite{Yuen2008,Bhargava2014,Lee2014}.
3D printed devices have been used for neuroengineering applications\cite{Tek2008}, inexpensive and high-throughput reactionware,\cite{Kitson2012,Symes2012,Kitson2013,Kitson2014}, culturing and imaging arrays of seedlings\cite{Busch2012}, measuring dopamine and ATP levels in biological samples with an integrated electrode\cite{Erkal2014}, or plate reader\cite{Chen2014}, and a bacteria separation flow assay\cite{Lee2014a,Lee2015}. 
Other 3D-printed fluidic devices include pneumatic valves\cite{Au2015} a custom NMR cell\cite{Causier2015}, a rapid reconstitution package for lyophilized drugs\cite{Chi2014} and flow plates for a water electrolysis system\cite{Chisholm2014}.

Printing is currently limited in choice of substrate compatible with the 3D printing process.
Substrate options include many proprietary formulations which have been successfully used in a variety of applications.
New techniques for using 3D-printed molds to produce devices\cite{Mcdonald2002,Gregory2013,King2014,Comina2014a,Kamei2015} are also being developed, including fugitive ink methods\cite{Therriault2003,Miller2012,Bhargava2015}.
To date, there are no widely available methods or materials to facilitate direct printing of gas-permeable materials, although this area is actively being explored\cite{Femmer2014a}.
Microfluidic cell culture devices are most commonly cast in PDMS as it is a convenient material for cell studies due to its biocompatibility, optical properties, and gas permeability, facilitating oxygen control of cell environments\cite{Sia2003,Brennan2014}.
\DIFaddbegin \DIFadd{In this study, a larger 24 well version was developed and optimized which includes several key improvements over the previous 6-well version.}\DIFaddend 

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

Previously, we developed multiwell inserts for 6-well plates that controlled oxygen in a standard off-the shelf well plate \cite{Oppegard2009, Oppegard2010}.
These \DIFaddbegin \DIFadd{6-well }\DIFaddend devices were completely cast from PDMS and fabricated in a multiple bonding procedure.
In addition, tubing was used to connect each pillar which became quite cumbersome when moving to a newer 24-well version.
Utilizing 3D printing for the fabrication allowed further features to be incorporated such as integrated distribution channels to eliminate the connection tubings between wells and hose barbs for better tubing connections, while eliminating fabrication time and failure rate.
Although available 3D printable materials are gas-impermeable, the addition of a PDMS membrane following printing of the passive microfluidic network is a simple addition allowing gas transfer. 
In this case, having a gas-impermeable material for the bulk is advantageous as it reduces unwanted gas transfer from the bulk material prior to the gas exchange interface.
The previous PDMS devices were Parylene coated along the convection channels to eliminate exchange of gas from the PDMS bulk, which again added to their complexity and is no longer needed.
Convection and distribution of the gas is done in the impermeable material, eliminating dilution of the gas before reaching the diffusion layer. 

% You may title this section "Methods" or "Models". 
% "Models" is not a valid title for PLoS ONE authors. However, PLoS ONE
% authors may use "Analysis" 
\section*{Materials and Methods}
\subsection*{Design of insert}

The device was designed to integrate with a multiwell format, specifically an off-the-shelf 24-well plate. 
The 24-well plate insert was designed to control gas in 4 rows of 6 wells each. 
Each of the 4 rows can be controlled independently from an input and also incorporates an integrated distribution network and hose barbs to simplify device operation.
The pillars extend into each well leaving a $\sim$500 $\mu$m gap \DIFdelbegin \DIFdel{for media }\DIFdelend between the diffusion membrane and the culture surface\DIFdelbegin \DIFdel{at the bottom of the well}\DIFdelend \DIFaddbegin \DIFadd{.
This gap allows space for $\sim$0.17 mL of media}\DIFaddend .
Diffusion occurs rapidly across this gap allowing control of the dissolved gas environment around the cells. 
A distribution network stems from the central input that equalizes the flow along each path length by varying the channel width to the proximal, intermediate, and distal wells (Fig.~\ref{fig1}).
The device also features a pipe within a pipe design so that gas flow enters and leaves the diffusion area in a uniform, and symmetrical flow pattern, which would not be possible with standard lithography and demonstrates the capabilities of 3D printing (Fig.~\ref{fig1}).

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

\subsection*{Fabrication of the insert}

CAD models were designed in Autodesk and Blender and printed via stereolithography in Watershed XC by Fineline Prototyping.
The 3D part contained the microfluidic delivery channels, and was completed by adhering a gas-permeable membrane of PDMS to enable diffusion of gas to the culture area. 
The PDMS membranes were fabricated by spin coating 10:1 PDMS (Sylgard 184) on a silicon wafer at 900 RPM to a thickness of $\sim$100 $\mu$m and curing at $70\,^{\circ}$C for 30 minutes.
The PDMS membrane was cut to size and attached to the 3D-printed network with an additional, thin layer of PDMS that was applied as an adhesive to the membrane, secured in position on the end of each pillar, and allowed to cure in place.

\subsection*{Oxygen characterization}

Oxygen was measured with PtOEPK (Pt(II) Octaethylporphine ketone) planar sensors that were fixed to the bottom of a 24-well plate.
Sensors were prepared as discussed previously \cite{Sinkala2010,Rexius-Hall2014}. 
Briefly, polystyrene was dissolved in toluene to form a solution to which PtOEPK (Frontier Scientific) was mixed in before spin coating to a thin layer and allowing the toluene to evaporate.
\DIFdelbegin \DIFdel{The intensity of the sensor was measured with via fluorescence microscopy and correlated to the concentration of oxygen with }\DIFdelend \DIFaddbegin \DIFadd{Five calibration points were fitted to a two-site model\mbox{%DIFAUXCMD
\cite{Carraway1991,Wang2014}
}%DIFAUXCMD
of the }\DIFaddend Stern-Volmer \DIFdelbegin \DIFdel{analysis}\DIFdelend \DIFaddbegin \DIFadd{relationship which was used to correlate sensor intensities with oxygen concentration}\DIFaddend .

Gas was pulled through the device with negative pressure as a precaution to avoid bulging or detaching membranes, as well as bubble formation in the culture media.
The outlet ports were connected to a water aspirator which pulled gas through the device from the inlet ports via a flow meter (FL-5311G; Omega) set at 50 ccm.
The inlet tubing was placed in an open cone that was flooded with gas from a tank with a flow rate of 30 ccm which exceed the vacuum flow rate (12.5 ccm per 6-well network) so that the gas of interest was pulled into the inlet rather than room air due to the open connection.
In this way, the pressure, and therefore flow rate, was equal across the 4 networks without having to balance flow from 4 pressurized sources, yet different gases of interest can be perfused via vacuum.

Initially the inlets are fed with a 5\% \ce{CO2}, balanced air tank until the intensity stabilized.
The inlets were then switched to the control gas of either 0, 5, 10, or 21\% \ce{O2}, each with 5\% \ce{CO2} and balanced with \ce{N2}.
Intensity measurements were then taken every five minutes for six hours.
All gas tanks used in the oxygen characterization were 5\% \ce{CO2}  in addition to the desired gas mix in anticipation of cell culture experiments (where \ce{CO2} is necessary to buffer the culture media) as \ce{CO2} can alter the fluorescence of the PtOEPK.
The this entire procedure was repeated three independent times. 

\subsection*{Cell culture}

\DIFaddbegin \DIFadd{The assembled device was sterilized by spraying with 70\% ethanol solution and placed in a biosaftey hood with UV lights overnight.
}\DIFaddend Human lung adenocarcinoma (A549) cells were seeded at 30,000 cells per well in a 24-well plate.
Cells were cultured in DMEM supplemented with 10\% FBS.
After reaching $\sim$70\% confluency, the 24-well insert was placed in the plate and the gases were perfused through the device in the same scheme as in the oxygen characterization.
Each row of six wells experienced either 0\%, 5\%, 10\% or 21\% \ce{O2}, with 5\% \ce{CO2} and balanced nitrogen.
The assembly was placed in an incubator at $37\,^{\circ}$C for six hours. 

\subsection*{Quantitative PCR}

Following six hours of oxygen modulation, the 24-well oxygen control insert was removed and culture media was aspirated.
\DIFaddbegin \DIFadd{No contamination of the culture was observed.
}\DIFaddend Cells in each well were washed twice with PBS, and 300 $\mu$L of a lysis solution consisting of 10 $\mu$L of $\beta$-mercaptoethanol (Sigma Aldrich) per 1 mL of lysis buffer (PureLink RNA Mini Kit; Invitrogen) was added to each well.
The lysate from each well was collected as a sample.
RNA was extracted according to the PureLink RNA Mini Kit manufacturer’s instructions.

Synthesis of cDNA was performed using the High-Capacity cDNA Reverse Transcription Kit (Applied Biosystems), and quantitative PCR was carried out on ABI PRISM 700O (Applied Biosystems) in 25 $\mu$L reactions using Taqman Gene Expression Assays.
Beta-2-microglobulin (B2M) served as the endogenous control for calculations of relative gene expression.
Six technical replicates from the 6-well control unit were processed for each of four oxygen conditions (0\%, 5\%, 10\% and 21\% \ce{O2}) in three independent experiments.

\subsection*{Statistical analysis}

Cell culture experiments were repeated three independent times. Data are expressed as the mean $\pm$ SD. One-way ANOVA with Tukey’s multiple comparison post-test performed by Prism 5 (Graphpad) determined significance.

% For figure citations, please use "Fig." instead of "Figure".
%Nulla mi mi, Fig.~\ref{fig1} venenatis sed ipsum varius, volutpat euismod diam. Proin rutrum vel massa non gravida. Quisque tempor sem et dignissim rutrum. Lorem ipsum dolor sit amet, consectetur adipiscing elit. Morbi at justo vitae nulla elementum commodo eu id massa. In vitae diam ac augue semper tincidunt eu ut eros. Fusce fringilla erat porttitor lectus cursus, \nameref{S1_Video} vel sagittis arcu lobortis. Aliquam in enim semper, aliquam massa id, cursus neque. Praesent faucibus semper libero.

%\begin{enumerate}
%\item{react}
%\item{diffuse free particles}
%\item{increment time by dt and go to 1}
%\end{enumerate}

% Results and Discussion can be combined.
\section*{Results}
\subsection*{Oxygen control}
Oxygen control in the 24-well insert device was quantified with a platinum-based (PtOEPK) planar oxygen sensor placed at the bottom of the well, as shown in Fig.~\ref{fig2}.
The device reaches steady state in 30 minutes and can then hold the oxygen level near 0\% \ce{O2} indefinitely, while 95\% \ce{N2}, 5\% \ce{CO2} is pumped through the device.
A different gas condition can be used in each separate iteration of the 6-well unit allowing 6 technical replicates of up to 4 different gas conditions in one 24-well plate\DIFdelbegin \DIFdel{(Fig.
~\ref{fig2}). }\DIFdelend \DIFaddbegin \DIFadd{.
}\DIFaddend There was little variation in the oxygen levels measured in each of the 6 wells controlled by a single inlet, demonstrating the distribution network worked effectively.

\begin{figure}[h]
\caption{
{\bf Oxygen Characterization.} 
\DIFdelbeginFL \DIFdelFL{(A) }\DIFdelendFL Time course data of \DIFaddbeginFL \DIFaddFL{four }\DIFaddendFL oxygen \DIFdelbeginFL \DIFdelFL{being evacuated from the culture area as 0\% oxygen gas is perfused through the device.
Error bars are the standard deviation N=3.
(B) Four oxygen }\DIFdelendFL conditions are demonstrated in a 24-well plate.
Each 6-well row of the plate can be controlled independently.  
\DIFdelbeginFL \DIFdelFL{Mean }\DIFdelendFL \DIFaddbeginFL \DIFaddFL{Error bars are the standard deviation }\DIFaddendFL N=\DIFdelbeginFL \DIFdelFL{3 error bars not included.
}\DIFdelendFL \DIFaddbeginFL \DIFaddFL{3.
}\DIFaddendFL }
\label{fig2}
\end{figure}

\subsection*{Bioverifcation}

Oxygen levels of 21\%, 10\%, 5\%, and 0\% were applied to each set of 6 wells in which A549 cells were cultured.
Measurement of relative gene expression confirmed biological responsiveness of cells under the device’s control.
The device’s ability to control the gas environment was demonstrated with hypoxia-induced upregulation of VEGFA mRNA in the A549 cells (Fig.~\ref{fig3}).  Quantitative PCR showed a significant increase in the relative gene expression of VEGFA in wells exposed to 0\% \ce{O2} for 6 hours as compared to 21\% \ce{O2}. Hypoxia-induced alterations in gene expression usually indicate a HIF-transduced hypoxic signal in cells.
When a HIF transcription factor undergoes nuclear translocation, it can initiate transcription of genes by binding to the hypoxia response element (HRE)\cite{Lee2004} on its target genes.
VEGFA has previously been shown to have a functional HRE, and upregulation has been observed in A549 cells under hypoxic conditions\cite{RohrerBley2011}.
\DIFdelbegin %DIFDELCMD < 

%DIFDELCMD < %%%
\DIFdelend \DIFaddbegin \DIFadd{The 6 h time point was chosen based on the HIF-1$\alpha$ timecourse in A549 cells. 
HIF-1$\alpha$ protein levels are maximal at 4 h and steeply decrease by 16 h\mbox{%DIFAUXCMD
\cite{Li2006}
}%DIFAUXCMD
. 
Based on the known time course, we looked at a time point slightly delayed from the 4 h peak to account for transcription of the downstream target genes.
}\DIFaddend \begin{figure}[h]
\caption{
{\bf PCR Data.}  VEGFA expression in A549 cells after exposure to different oxygen conditions set-up by the insert device. Data are expressed as mean $\pm$ SD, N=3.
}
\label{fig3}
\end{figure}

\subsection*{Discussion}
This new iteration of the multi-well insert for oxygen control maintains the convenient features of the previous design while improving distribution and interfacing with tubing due to the 3D-printed element.
Oxygen control is performed in an off-the-shelf culture plate allowing standard protocols to be used for analysis assays or imaging where additional protocols are often required when cells are seeded within microfluidic chips.
The VEGFA gene expression in A549 cells confirms a biological response using the multi-well insert.

This 3D-printed device improves on our previous design in a number of ways.
First, the fabrication is greatly simplified. 
No microfabrication, PDMS molding or Parylene coating is required.
Additionally, the non-permanent adhesion of membranes to the 3D-part allow them to be removed and replaced if they are damaged.
In PDMS devices the layers are bonded permanently via plasma bonding so damage to a membrane is not repairable.
3D-printing also enables higher levels of intricacy without any additional fabrication, allowing us to include the distribution network, overlapping of channels in the z-axis, and the 'pipe within a pipe' design. 
A comparable PDMS device would require several additional microfabricated layers to be manually aligned to reproduce just the distribution network.

Moving forward with additive manufacturing of microfluidic devices is desirable as it will enable highly integrated designs without any additional fabrication.
For this device an in-device gas mixer could allow more conditions in a single plate, perhaps even one per well or even gradients within wells while reducing the number of gas tanks required as inputs.
This design could also be applied to higher format plates such as 96-well plates.

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

% Please do not create a heading level below \subsection. For 3rd level headings, use \paragraph{}. 
%For more information, see \nameref{S1_Text}.

%\section*{Supporting Information}

% Include only the SI item label in the subsection heading. Use the \nameref{label} command to cite SI items in the text.
%\subsection*{S1 Video}
%\label{S1_Video}
%{\bf Bold the first sentence.}  Maecenas convallis mauris sit amet sem ultrices gravida. Etiam eget sapien nibh. %Sed ac ipsum eget enim egestas ullamcorper nec euismod ligula. Curabitur fringilla pulvinar lectus consectetur %pellentesque.

%\subsection*{S1 Text}
%\label{S1_Text}
%{\bf Lorem Ipsum.} Maecenas convallis mauris sit amet sem ultrices gravida. Etiam eget sapien nibh. Sed ac %ipsum eget enim egestas ullamcorper nec euismod ligula. Curabitur fringilla pulvinar lectus consectetur %pellentesque.

%\subsection*{S1 Fig}
%\label{S1_Fig}
%{\bf Lorem Ipsum.} Maecenas convallis mauris sit amet sem ultrices gravida. Etiam eget sapien nibh. Sed ac %ipsum eget enim egestas ullamcorper nec euismod ligula. Curabitur fringilla pulvinar lectus consectetur %pellentesque.

%\subsection*{S2 Fig}
%\label{S2_Fig}
%{\bf Lorem Ipsum.} Maecenas convallis mauris sit amet sem ultrices gravida. Etiam eget sapien nibh. Sed ac %ipsum eget enim egestas ullamcorper nec euismod ligula. Curabitur fringilla pulvinar lectus consectetur %pellentesque.

%\subsection*{S1 Table}
%\label{S1_Table}
%{\bf Lorem Ipsum.} Maecenas convallis mauris sit amet sem ultrices gravida. Etiam eget sapien nibh. Sed ac %ipsum eget enim egestas ullamcorper nec euismod ligula. Curabitur fringilla pulvinar lectus consectetur %pellentesque.

%\section*{Acknowledgments}
%This work funded by NSF 1253060.

\nolinenumbers

%\section*{References}
\bibliographystyle{plos2015.bst}
\bibliography{references}

\end{document}

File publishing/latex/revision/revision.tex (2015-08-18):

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

\documentclass[10pt,letterpaper]{article}
\usepackage[top=0.85in,left=2.75in,footskip=0.75in]{geometry}

% Use adjustwidth environment to exceed column width (see example table in text)
\usepackage{changepage}

% Use Unicode characters when possible
\usepackage[utf8]{inputenc}

% textcomp package and marvosym package for additional characters
\usepackage{textcomp,marvosym}

% fixltx2e package for \textsubscript
\usepackage{fixltx2e}

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

% cite package, to clean up citations in the main text. Do not remove.
\usepackage{cite}

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

% line numbers
\usepackage[right]{lineno}

% ligatures disabled
\usepackage{microtype}
\DisableLigatures[f]{encoding = *, family = * }

% rotating package for sideways tables
\usepackage{rotating}

% Remove comment for double spacing
%\usepackage{setspace} 
%\doublespacing

% Text layout
\raggedright
\setlength{\parindent}{0.5cm}
\textwidth 5.25in 
\textheight 8.75in

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

% Use the PLoS provided BiBTeX style
\bibliographystyle{plos2015}

% Remove brackets from numbering in List of References
\makeatletter
\renewcommand{\@biblabel}[1]{\quad#1.}
\makeatother

% Leave date blank
\date{}

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

%% Include all macros below

\newcommand{\lorem}{{\bf LOREM}}
\newcommand{\ipsum}{{\bf IPSUM}}

%% END MACROS SECTION

\begin{document}
\vspace*{0.35in}

% Title must be 250 characters or less.
% Please capitalize all terms in the title except conjunctions, prepositions, and articles.
\begin{flushleft}
{\Large
\textbf\newline{A 3D-Printed Oxygen Control Insert for a 24-Well Plate}
}
\newline
% Insert author names, affiliations and corresponding author email (do not include titles, positions, or degrees).
\\
Martin D. Brennan\textsuperscript{1},
Megan L. Rexius-Hall\textsuperscript{1},
David T. Eddington\textsuperscript{1,*},
\\
\bigskip
\bf{1} Dept of Bioengineering, University of Illinois at Chicago, Chicago, Illinois, USA
\\
\bigskip

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

\end{flushleft}
% Please keep the abstract below 300 words
\section*{Abstract}
3D printing has emerged as a method for directly printing complete microfluidic devices, although printing materials have been limited to oxygen-impermeable materials.
We demonstrate the addition of gas permeable PDMS (Polydimethylsiloxane) membranes to 3D-printed microfluidic devices as a means to enable oxygen control cell culture studies.
The incorporation of a 3D-printed device and gas-permeable membranes was demonstrated on a 24-well oxygen control device for standard multiwell plates.
The direct printing allows integrated distribution channels and device geometries not possible with traditional planar lithography.
With this device, four different oxygen conditions were able to be controlled, and six wells were maintained under each oxygen condition. 
We demonstrate enhanced transcription of the gene VEGFA (vascular endothelial growth factor A) with decreasing oxygen levels in human lung adenocarcinoma cells.
This is the first 3D-printed device incorporating gas permeable membranes to facilitate oxygen control in cell culture.
\linenumbers

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

Printing is currently limited in choice of substrate compatible with the 3D printing process.
Substrate options include many proprietary formulations which have been successfully used in a variety of applications.
New techniques for using 3D-printed molds to produce devices\cite{Mcdonald2002,Gregory2013,King2014,Comina2014a,Kamei2015} are also being developed, including fugitive ink methods\cite{Therriault2003,Miller2012,Bhargava2015}.
To date, there are no widely available methods or materials to facilitate direct printing of gas-permeable materials, although this area is actively being explored\cite{Femmer2014a}.
Microfluidic cell culture devices are most commonly cast in PDMS as it is a convenient material for cell studies due to its biocompatibility, optical properties, and gas permeability, facilitating oxygen control of cell environments\cite{Sia2003,Brennan2014}.
In this study, a larger 24 well version was developed and optimized which includes several key improvements over the previous 6-well version.

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

Previously, we developed multiwell inserts for 6-well plates that controlled oxygen in a standard off-the shelf well plate \cite{Oppegard2009, Oppegard2010}.
These 6-well devices were completely cast from PDMS and fabricated in a multiple bonding procedure.
In addition, tubing was used to connect each pillar which became quite cumbersome when moving to a newer 24-well version.
Utilizing 3D printing for the fabrication allowed further features to be incorporated such as integrated distribution channels to eliminate the connection tubings between wells and hose barbs for better tubing connections, while eliminating fabrication time and failure rate.
Although available 3D printable materials are gas-impermeable, the addition of a PDMS membrane following printing of the passive microfluidic network is a simple addition allowing gas transfer. 
In this case, having a gas-impermeable material for the bulk is advantageous as it reduces unwanted gas transfer from the bulk material prior to the gas exchange interface.
The previous PDMS devices were Parylene coated along the convection channels to eliminate exchange of gas from the PDMS bulk, which again added to their complexity and is no longer needed.
Convection and distribution of the gas is done in the impermeable material, eliminating dilution of the gas before reaching the diffusion layer. 

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

The device was designed to integrate with a multiwell format, specifically an off-the-shelf 24-well plate. 
The 24-well plate insert was designed to control gas in 4 rows of 6 wells each. 
Each of the 4 rows can be controlled independently from an input and also incorporates an integrated distribution network and hose barbs to simplify device operation.
The pillars extend into each well leaving a $\sim$500 $\mu$m gap between the diffusion membrane and the culture surface.
This gap allows space for $\sim$0.17 mL of media.
Diffusion occurs rapidly across this gap allowing control of the dissolved gas environment around the cells. 
A distribution network stems from the central input that equalizes the flow along each path length by varying the channel width to the proximal, intermediate, and distal wells (Fig.~\ref{fig1}).
The device also features a pipe within a pipe design so that gas flow enters and leaves the diffusion area in a uniform, and symmetrical flow pattern, which would not be possible with standard lithography and demonstrates the capabilities of 3D printing (Fig.~\ref{fig1}).

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

\subsection*{Fabrication of the insert}

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

\subsection*{Oxygen characterization}

Oxygen was measured with PtOEPK (Pt(II) Octaethylporphine ketone) planar sensors that were fixed to the bottom of a 24-well plate.
Sensors were prepared as discussed previously \cite{Sinkala2010,Rexius-Hall2014}. 
Briefly, polystyrene was dissolved in toluene to form a solution to which PtOEPK (Frontier Scientific) was mixed in before spin coating to a thin layer and allowing the toluene to evaporate.
Five calibration points were fitted to a two-site model\cite{Carraway1991,Wang2014} of the Stern-Volmer relationship which was used to correlate sensor intensities with oxygen concentration.

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

\subsection*{Cell culture}

The assembled device was sterilized by spraying with 70\% ethanol solution and placed in a biosaftey hood with UV lights overnight.
Human lung adenocarcinoma (A549) cells were seeded at 30,000 cells per well in a 24-well plate.
Cells were cultured in DMEM supplemented with 10\% FBS.
After reaching $\sim$70\% confluency, the 24-well insert was placed in the plate and the gases were perfused through the device in the same scheme as in the oxygen characterization.
Each row of six wells experienced either 0\%, 5\%, 10\% or 21\% \ce{O2}, with 5\% \ce{CO2} and balanced nitrogen.
The assembly was placed in an incubator at $37\,^{\circ}$C for six hours. 

\subsection*{Quantitative PCR}

Following six hours of oxygen modulation, the 24-well oxygen control insert was removed and culture media was aspirated.
No contamination of the culture was observed.
Cells in each well were washed twice with PBS, and 300 $\mu$L of a lysis solution consisting of 10 $\mu$L of $\beta$-mercaptoethanol (Sigma Aldrich) per 1 mL of lysis buffer (PureLink RNA Mini Kit; Invitrogen) was added to each well.
The lysate from each well was collected as a sample.
RNA was extracted according to the PureLink RNA Mini Kit manufacturer’s instructions.

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

\subsection*{Statistical analysis}

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

% Results and Discussion can be combined.
\section*{Results}
\subsection*{Oxygen control}
Oxygen control in the 24-well insert device was quantified with a platinum-based (PtOEPK) planar oxygen sensor placed at the bottom of the well, as shown in Fig.~\ref{fig2}.
The device reaches steady state in 30 minutes and can then hold the oxygen level near 0\% \ce{O2} indefinitely, while 95\% \ce{N2}, 5\% \ce{CO2} is pumped through the device.
A different gas condition can be used in each separate iteration of the 6-well unit allowing 6 technical replicates of up to 4 different gas conditions in one 24-well plate.
There was little variation in the oxygen levels measured in each of the 6 wells controlled by a single inlet, demonstrating the distribution network worked effectively.

\begin{figure}[h]
\caption{
{\bf Oxygen Characterization.} 
Time course data of four oxygen conditions are demonstrated in a 24-well plate.
Each 6-well row of the plate can be controlled independently.  
Error bars are the standard deviation N=3.
}
\label{fig2}
\end{figure}

\subsection*{Bioverifcation}

Oxygen levels of 21\%, 10\%, 5\%, and 0\% were applied to each set of 6 wells in which A549 cells were cultured.
Measurement of relative gene expression confirmed biological responsiveness of cells under the device’s control.
The device’s ability to control the gas environment was demonstrated with hypoxia-induced upregulation of VEGFA mRNA in the A549 cells (Fig.~\ref{fig3}).  Quantitative PCR showed a significant increase in the relative gene expression of VEGFA in wells exposed to 0\% \ce{O2} for 6 hours as compared to 21\% \ce{O2}. Hypoxia-induced alterations in gene expression usually indicate a HIF-transduced hypoxic signal in cells.
When a HIF transcription factor undergoes nuclear translocation, it can initiate transcription of genes by binding to the hypoxia response element (HRE)\cite{Lee2004} on its target genes.
VEGFA has previously been shown to have a functional HRE, and upregulation has been observed in A549 cells under hypoxic conditions\cite{RohrerBley2011}.
The 6 h time point was chosen based on the HIF-1$\alpha$ timecourse in A549 cells. 
HIF-1$\alpha$ protein levels are maximal at 4 h and steeply decrease by 16 h\cite{Li2006}. 
Based on the known time course, we looked at a time point slightly delayed from the 4 h peak to account for transcription of the downstream target genes.
\begin{figure}[h]
\caption{
{\bf PCR Data.}  VEGFA expression in A549 cells after exposure to different oxygen conditions set-up by the insert device. Data are expressed as mean $\pm$ SD, N=3.
}
\label{fig3}
\end{figure}

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

\section*{Supporting Information}

\subsection*{S1 Dataset}
\label{S1 Dataset}
{\bf S1 Dataset. Oxygen Characterization Dataset.} This dataset consists of intensity values of the oxygen sensors as well as the analyzed oxygen values.

\subsection*{S2 Dataset}
\label{S2 Dataset}
{\bf S2 Dataset. VEGF Dataset} This dataset consists of quantitative real-time PCR for genes VEGFA and B2M.

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

%\section*{Acknowledgments}
%This work funded by NSF 1253060.

\nolinenumbers

%\section*{References}
\bibliographystyle{plos2015.bst}
\bibliography{references}

\end{document}

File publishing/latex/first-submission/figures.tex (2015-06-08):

\documentclass[]{article}

\usepackage{graphicx}

%opening
\title{Figures for  3-D printed oxygen devices}
\author{}

\begin{document}

%\maketitle

\section{figures}

\begin{figure}[H]
 
\caption{
{\bf Design of 24-well Insert Device.}
(A) Rendering of whole 3D printed part.
An inlet and outlet barb allows perfusion of gas to control 6 wells.
(B) At the bottom of each pillar gas entering from the outer channel flows along the PDMS membrane (blue), which is supported by micropillars, and exhausts via the inner pipe.
Diffusion occurs rapidly through the PDMS membrane to the cell culture spaced 500 $\mu$m away at the bottom of the well.
(C) Cross-section demonstrating how the microfluidic distribution network and double pipes are connected. 
The two adjacent mirrored distribution networks are spaced 1 mm apart along the z-axis allowing them to overlap and enter the separate vertical pipes.
The arrows indicate the flow direction.
The incoming gas enters the outer pipe on its way to the bottom of the well and returns through the inner pipe.
(D) Photo of the device with dyed channels in a 24-well plate.
(E) Photo of the device from the bottom with four independent channel networks.
(F) Photo of the printed distribution networks.
}
\label{figure1}
\end{figure}

\begin{figure}[H]

\caption{
{\bf Oxygen Characterization.} 
(A) Time course data of oxygen being evacuated from the culture area as 0\% oxygen gas is perfused through the device.
Error bars are the standard deviation N=3.
(B) Four oxygen conditions are demonstrated in a 24-well plate.
Each 6-well row of the plate can be controlled independently.  
Mean N=3 error bars not included.
}
\label{figure2}
\end{figure}

\begin{figure}[H]

\caption{
{\bf PCR Data.}  VEGFA expression in A549 cells after exposure to different oxygen conditions set-up by the insert device. Data are expressed as mean $\pm$ SD, N=3.
}
\label{figure3}
\end{figure}

%\begin{abstract}

%\end{abstract}

%\section{}

\end{document}

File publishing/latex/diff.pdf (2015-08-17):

## A 3D-Printed Oxygen Control Insert for a 24-Well Plate

Martin D. Brennan¹

, Megan L. Rexius-Hall¹

, David T. Eddington¹,*
,

1 Dept of Bioengineering, University of Illinois at Chicago, Chicago, Illinois, USA

* dte@uic.edu

## Abstract

Recently 3D printing has emerged as a method for directly printing complete microfluidic devices, although printing materials have been limited to oxygen-impermeable materials. We demonstrate the addition of gas permeable PDMS (Polydimethylsiloxane) membranes to 3D-printed microfluidic devices as a means to enable oxygen control cell culture studies. The incorporation of a 3D-printed device and gas-permeable membranes was demonstrated on a 24-well oxygen control device for standard multiwell plates. The direct printing allows integrated distribution channels and device geometries not possible with traditional planar lithography. With this device, four different oxygen conditions were able to be controlled, and six wells were maintained under each oxygen condition. We demonstrate enhanced transcription of the gene VEGFA (vascular endothelial growth factor A) with decreasing oxygen levels in human lung adenocarcinoma cells. This is the first 3D-printed device that can be functionalized to control oxygen ✿✿✿✿✿✿✿✿✿✿✿
incorporating✿✿✿✿

gas✿✿✿✿✿✿✿✿✿✿

permeable ✿✿✿✿✿✿✿✿✿✿ membranes✿✿

to✿✿✿✿✿✿✿✿✿

facilitate

✿✿✿✿✿✿

oxygen✿✿✿✿✿✿✿

control in cell culture.

## Introduction

Here we report on the development of 3D-printed microfluidic devices for the control of oxygen in cell culture microenvironments. We demonstrate a device that nests into a 24-well culture plate to control gas in each row of the plate independently of the incubator’s condition. This expands on our previous work of a device fabricated using PDMS molds and planar lithography for 6-well plates [1, 2]. The ability to independently control oxygen across each row of the plate enables more efficient experiments as a separate incubator or hypoxic chamber is not needed for each condition.
3D printing of microfluidic devices enables rapid, one-step fabrication of complex designs infeasible to make with planar lithography and replica molding techniques [3, 4]. In addition, planar lithography is time consuming, requires specialized equipment and facilities, and has a high failure rate. It is not unusual for microfluidic labs to make ten microfluidic devices to guarantee one will work properly. On the other hand, 3D CAD printing allows for unambiguous specifications and nearly eliminates time and effort spent on fabrication which may be outsourced to a 3D printing company for around $200/device [5]. 3D printing also allows integration of complex geometries not possible with planar lithography, such as hose barbs and luer fittings. Dissemination and distributed production is also vastly simplified due to easy sharing of the design as a CAD file. Due to these inherent advantages 3D printing has emerged as a method for directly printing complete microfluidic devices [5–9]. Many prototypical microfluidic
PLOS | 1/10

device features have been recreated with 3D printing as a proof of concept for this new fabrication technique [5, 8] including modular re-configurable units [9–11]. 3D printed devices have been used for neuroengineering applications [12], inexpensive and high-throughput reactionware, [13–16], culturing and imaging arrays of seedlings [17], measuring dopamine and ATP levels in biological samples with an integrated electrode [18], or plate reader [7], and a bacteria separation flow assay [19, 20]. Other 3D-printed fluidic devices include pneumatic valves [21] a custom NMR cell [22], a rapid reconstitution package for lyophilized drugs [23] and flow plates for a water electrolysis system [24].
Printing is currently limited in choice of substrate compatible with the 3D printing process. Substrate options include many proprietary formulations which have been successfully used in a variety of applications. New techniques for using 3D-printed molds to produce devices [25–29] are also being developed, including fugitive ink methods [30–32]. To date, there are no widely available methods or materials to facilitate direct printing of gas-permeable materials, although this area is actively being explored [33]. Microfluidic cell culture devices are most commonly cast in PDMS as it is a convenient material for cell studies due to its biocompatibility, optical properties, and gas permeability, facilitating oxygen control of cell environments [34, 35]. ✿✿
In✿✿✿✿

this✿✿✿✿✿✿

study,

✿

a✿✿✿✿✿✿

larger ✿✿

24✿✿✿✿ well✿✿✿✿✿✿✿

version✿✿✿✿ was✿✿✿✿✿✿✿✿✿

developed✿✿✿✿

and✿✿✿✿✿✿✿✿✿

optimized✿✿✿✿✿✿ which✿✿✿✿✿✿✿✿

includes ✿✿✿✿✿✿

several✿✿✿✿

key

✿✿✿✿✿✿✿✿✿✿✿✿

improvements✿✿✿✿

over✿✿✿✿

the✿✿✿✿✿✿✿✿

previous ✿✿✿✿✿✿

6-well ✿✿✿✿✿✿✿

version.
Oxygen control in cells studies is often overlooked by researchers, but important for mimicking conditions experienced by cells in vivo. Typically cell culture studies are performed at 21% oxygen, atmospheric oxygen conditions, although levels that cells experience in vivo are less than 21% [35]. For example, tumors are generally hypoxic as cancer cells rapidly outgrow their vasculature creating a poorly perfused, hypoxic inner region [36]. Studying cancer cells under controlled hypoxic conditions is important in understanding the pathophysiology because research has shown hypoxia may enhance aggressive phenotypes, tumor progression, metastasis, and resistance to therapy [37–39]. Hypoxia is known to alter the transcription of many genes which are under the activity of the HIF (hypoxia inducible factor) family of transcriptional factors [40–42]. To better study the role of oxygen levels in cancer gene expression, a gas controlled culture system is required.
Previously, we developed multiwell inserts for 6-well plates that controlled oxygen in a standard off-the shelf well plate [1, 2]. These ✿✿✿✿✿
6-well devices were completely cast from PDMS and fabricated in a multiple bonding procedure. In addition, tubing was used to connect each pillar which became quite cumbersome when moving to a newer 24-well version. Utilizing 3D printing for the fabrication allowed further features to be incorporated such as integrated distribution channels to eliminate the connection tubings between wells and hose barbs for better tubing connections, while eliminating fabrication time and failure rate. Although available 3D printable materials are gas-impermeable, the addition of a PDMS membrane following printing of the passive microfluidic network is a simple addition allowing gas transfer. In this case, having a gas-impermeable material for the bulk is advantageous as it reduces unwanted gas transfer from the bulk material prior to the gas exchange interface. The previous PDMS devices were Parylene coated along the convection channels to eliminate exchange of gas from the PDMS bulk, which again added to their complexity and is no longer needed. Convection and distribution of the gas is done in the impermeable material, eliminating dilution of the gas before reaching the diffusion layer.

Materials and Methods | 69
Design of insert | 70
The device was designed to integrate with a multiwell format, specifically an | 71
off-the-shelf 24-well plate. The 24-well plate insert was designed to control gas in 4 rows | 72
of 6 wells each. Each of the 4 rows can be controlled independently from an input and | 73
also incorporates an integrated distribution network and hose barbs to simplify device | 74
operation. The pillars extend into each well leaving a ∼500 µm gap for media between | 75
the diffusion membrane and the culture surfaceat the bottom of the well.✿✿✿✿✿ This✿✿✿✿
gap | 76

✿✿✿✿✿

allows✿✿✿✿✿✿

space ✿✿✿

for ✿✿✿✿✿ ∼0.17✿✿✿✿ mL✿✿
of✿✿✿✿✿✿ media. Diffusion occurs rapidly across this gap allowing | 77
control of the dissolved gas environment around the cells. A distribution network stems | 78
from the central input that equalizes the flow along each path length by varying the | 79
channel width to the proximal, intermediate, and distal wells (Fig. 1). The device also | 80
features a pipe within a pipe design so that gas flow enters and leaves the diffusion area | 81
in a uniform, and symmetrical flow pattern, which would not be possible with standard | 82
lithography and demonstrates the capabilities of 3D printing (Fig. 1). | 83

Figure 1. Design of 24-well Insert Device. (A) Rendering of whole 3D printed part. An inlet and outlet barb allows perfusion of gas to control 6 wells. (B) At the bottom of each pillar gas entering from the outer channel flows along the PDMS membrane (blue), which is supported by micropillars, and exhausts via the inner pipe. Diffusion occurs rapidly through the PDMS membrane to the cell culture spaced 500 µm away at the bottom of the well. (C) Cross-section demonstrating how the microfluidic distribution network and double pipes are connected. The two adjacent mirrored distribution networks are spaced 1 mm apart along the z-axis allowing them to overlap and enter the separate vertical pipes. The arrows indicate the flow direction. The incoming gas enters the outer pipe on its way to the bottom of the well and returns through the inner pipe. (D) Photo of the device with dyed channels in a 24-well plate.
(E) Photo of the device from the bottom with four independent channel networks. (F) Photo of the printed distribution networks.
Fabrication of the insert | 84
CAD models were designed in Autodesk and Blender and printed via stereolithography | 85
in Watershed XC by Fineline Prototyping. The 3D part contained the microfluidic | 86
delivery channels, and was completed by adhering a gas-permeable membrane of PDMS | 87
to enable diffusion of gas to the culture area. The PDMS membranes were fabricated by | 88
spin coating 10:1 PDMS (Sylgard 184) on a silicon wafer at 900 RPM to a thickness of | 89
∼100 µm and curing at 70 ◦C for 30 minutes. The PDMS membrane was cut to size and | 90
attached to the 3D-printed network with an additional, thin layer of PDMS that was | 91
applied as an adhesive to the membrane, secured in position on the end of each pillar, | 92
and allowed to cure in place. | 93
Oxygen characterization | 94
Oxygen was measured with PtOEPK (Pt(II) Octaethylporphine ketone) planar sensors | 95
that were fixed to the bottom of a 24-well plate. Sensors were prepared as discussed | 96
previously [43, 44]. Briefly, polystyrene was dissolved in toluene to form a solution to | 97
which PtOEPK (Frontier Scientific) was mixed in before spin coating to a thin layer | 98
and allowing the toluene to evaporate. The intensity of the sensor was measured with | 99
via fluorescence microscopy and correlated to the concentration of oxygen with ✿✿✿✿
Five 100

✿✿✿✿✿✿✿✿✿

calibration✿✿✿✿✿✿

points✿✿✿✿✿ were✿✿✿✿✿

fitted✿✿✿
to ✿

a✿✿✿✿✿✿✿✿

two-site✿✿✿✿✿✿✿✿✿✿✿✿✿✿✿ model [45, 46] of ✿✿✿ the✿

Stern-Volmer

analysis✿✿✿✿✿✿✿✿✿✿

relationship✿✿✿✿✿✿ which ✿✿✿✿ was ✿✿✿✿

used✿✿✿

to ✿✿✿✿✿✿✿✿

correlate✿✿✿✿✿✿

sensor✿✿✿✿✿✿✿✿✿

intensities✿✿✿✿✿ with✿✿✿✿✿✿✿

oxygen

✿✿✿✿✿✿✿✿✿✿✿✿

concentration.
Gas was pulled through the device with negative pressure as a precaution to avoid bulging or detaching membranes, as well as bubble formation in the culture media. The outlet ports were connected to a water aspirator which pulled gas through the device from the inlet ports via a flow meter (FL-5311G; Omega) set at 50 ccm. The inlet tubing was placed in an open cone that was flooded with gas from a tank with a flow rate of 30 ccm which exceed the vacuum flow rate (12.5 ccm per 6-well network) so that the gas of interest was pulled into the inlet rather than room air due to the open connection. In this way, the pressure, and therefore flow rate, was equal across the 4 networks without having to balance flow from 4 pressurized sources, yet different gases of interest can be perfused via vacuum.
Initially the inlets are fed with a 5% CO2
, balanced air tank until the intensity stabilized. The inlets were then switched to the control gas of either 0, 5, 10, or 21% O2
, 115
each with 5% CO2
and balanced with N2

. Intensity measurements were then taken every five minutes for six hours. All gas tanks used in the oxygen characterization were 5% CO2
in addition to the desired gas mix in anticipation of cell culture experiments (where CO2

is necessary to buffer the culture media) as CO2
can alter the fluorescence of the PtOEPK. The this entire procedure was repeated three independent times.

Cell culture

✿✿✿ The✿✿✿✿✿✿✿✿✿✿

assembled✿✿✿✿✿✿

device✿✿✿✿ was ✿✿✿✿✿✿✿✿

sterilized✿✿✿

by✿✿✿✿✿✿✿✿

spraying✿✿✿✿✿ with ✿✿✿✿

70%✿✿✿✿✿✿✿
ethanol✿✿✿✿✿✿✿✿

solution ✿✿✿

and✿✿✿✿✿✿✿

placed

✿✿

in ✿

a✿✿✿✿✿✿✿✿✿

biosaftey ✿✿✿✿✿
hood ✿✿✿✿ with✿✿✿✿ UV✿✿✿✿✿

lights✿✿✿✿✿✿✿✿✿✿

overnight. ✿Human lung adenocarcinoma (A549) cells were seeded at 30,000 cells per well in a 24-well plate. Cells were cultured in DMEM supplemented with 10% FBS. After reaching ∼70% confluency, the 24-well insert was placed in the plate and the gases were perfused through the device in the same scheme as in the oxygen characterization. Each row of six wells experienced either 0%, 5%, 10% or 21% O2

, with 5% CO2
and balanced nitrogen. The assembly was placed in an incubator at 37 ◦C for six hours.

Quantitative PCR

Following six hours of oxygen modulation, the 24-well oxygen control insert was removed and culture media was aspirated. No ✿✿✿✿✿✿✿✿✿✿✿✿✿✿✿

contamination✿✿✿

of ✿✿✿
the✿✿✿✿✿✿✿

culture✿✿✿✿ was

✿✿✿✿✿✿✿✿

observed.✿Cells in each well were washed twice with PBS, and 300 µL of a lysis solution consisting of 10 µL of β-mercaptoethanol (Sigma Aldrich) per 1 mL of lysis buffer (PureLink RNA Mini Kit; Invitrogen) was added to each well. The lysate from each well was collected as a sample. RNA was extracted according to the PureLink RNA Mini Kit manufacturer’s instructions.
Synthesis of cDNA was performed using the High-Capacity cDNA Reverse Transcription Kit (Applied Biosystems), and quantitative PCR was carried out on ABI PRISM 700O (Applied Biosystems) in 25 µL reactions using Taqman Gene Expression Assays. Beta-2-microglobulin (B2M) served as the endogenous control for calculations of relative gene expression. Six technical replicates from the 6-well control unit were processed for each of four oxygen conditions (0%, 5%, 10% and 21% O2

) in three
independent experiments.

Statistical analysis

Cell culture experiments were repeated three independent times. Data are expressed as the mean ± SD. One-way ANOVA with Tukey’s multiple comparison post-test

performed by Prism 5 (Graphpad) determined significance. | 148
Results | 149
Oxygen control | 150
Oxygen control in the 24-well insert device was quantified with a platinum-based | 151
(PtOEPK) planar oxygen sensor placed at the bottom of the well, as shown in Fig. 2. | 152
The device reaches steady state in 30 minutes and can then hold the oxygen level near | 153
0% O2

indefinitely, while 95% N2

, 5% CO2
is pumped through the device. A different | 154
gas condition can be used in each separate iteration of the 6-well unit allowing 6 | 155
technical replicates of up to 4 different gas conditions in one 24-well plate(Fig. 2). . | 156
There was little variation in the oxygen levels measured in each of the 6 wells controlled | 157
by a single inlet, demonstrating the distribution network worked effectively. | 158

Figure 2. Oxygen Characterization. (A) Time course data of ✿✿✿
four✿
oxygen being
evacuated from the culture area as 0% oxygen gas is perfused through the device. Error bars are the standard deviation N=3. (B) Four oxygen conditions are demonstrated in a 24-well plate. Each 6-well row of the plate can be controlled independently. Mean ✿✿✿✿✿
Error ✿✿✿✿

bars✿✿✿

are✿✿✿✿

the✿✿✿✿✿✿✿✿

standard✿✿✿✿✿✿✿✿✿

deviation✿N=3 error bars not included. ✿

3.✿

Bioverifcation | 159
Oxygen levels of 21%, 10%, 5%, and 0% were applied to each set of 6 wells in which | 160
A549 cells were cultured. Measurement of relative gene expression confirmed biological | 161
responsiveness of cells under the device’s control. The device’s ability to control the gas | 162
environment was demonstrated with hypoxia-induced upregulation of VEGFA mRNA in | 163
the A549 cells (Fig. 3). Quantitative PCR showed a significant increase in the relative | 164
gene expression of VEGFA in wells exposed to 0% O2

for 6 hours as compared to 21% 165 O2
. Hypoxia-induced alterations in gene expression usually indicate a HIF-transduced | 166
hypoxic signal in cells. When a HIF transcription factor undergoes nuclear translocation, | 167
it can initiate transcription of genes by binding to the hypoxia response element | 168
(HRE) [47] on its target genes. VEGFA has previously been shown to have a functional | 169
HRE, and upregulation has been observed in A549 cells under hypoxic conditions [48]. | 170

The ✿✿✿✿✿

6✿✿

h ✿✿✿✿

time✿✿✿✿✿✿

point ✿✿✿ was✿✿✿✿✿✿✿

chosen ✿✿✿✿✿

based✿✿✿

on✿✿✿✿
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

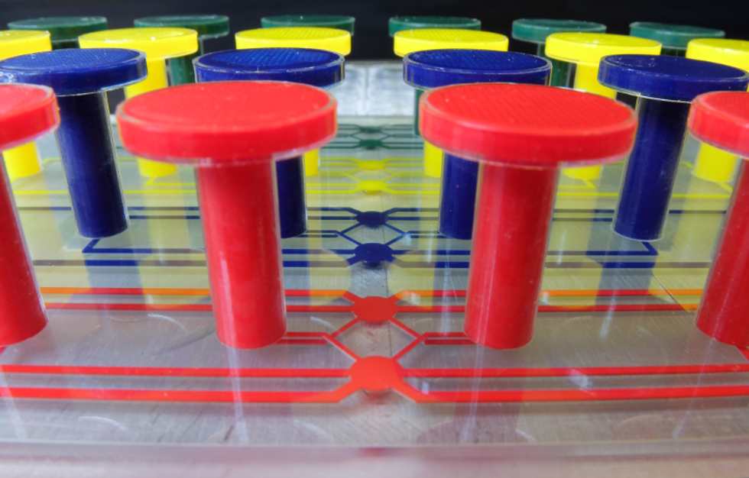
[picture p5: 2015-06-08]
publishing/figures/striking-image.tiff

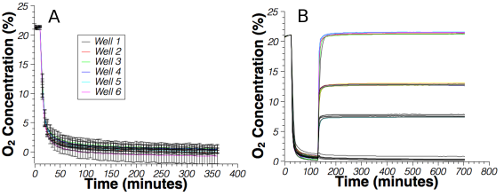
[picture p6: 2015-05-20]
publishing/latex/first-submission/Fig2.tiff

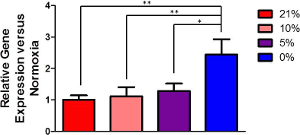
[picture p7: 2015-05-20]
publishing/latex/first-submission/Fig3.tiff

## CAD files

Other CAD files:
CAD-working-files/2d-distro-template.dwg
CAD-working-files/2D-network.dwg

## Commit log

2015-07-14 added matlab files
    [data.csv]
2015-08-10 added data
    [analyzed-oxygen-values-150805.csv, analyzed-oxygen-values-150807.csv, average.csv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]
2015-08-11 fixed std output
    [std.csv]
2015-08-13 n3 added
    [analyzed-oxygen-values-150812.csv, average.csv, calibration-intensities.csv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]
2015-08-17 added vegf data
    [VEGF_data.xlsx, VEGF_data_plotted.xlsx, analyzed-oxygen-values-150812.csv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]
2015-09-09 exported stl
